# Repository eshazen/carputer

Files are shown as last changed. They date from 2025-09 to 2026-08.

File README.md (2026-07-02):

# carputer

Car computer with display and GPS in DIN enclosure

Proposed functions:

* Clock (updated by GPS)
* Nearest town and potentially other geographical features
* Outside temperature

Front panel would have a display, a couple of buttons/knobs
and a USB plug for power from the stereo plus software updates
using Arduino boot loader.

See (Data/README.md)[Data/README.md] for data details and ideas.

## Implementation notes

On the MKR Zero board, there are only a few pins which can be used for
interrupts.  See
[docs](https://docs.arduino.cc/language-reference/en/functions/external-interrupts/attachInterrupt/).
These pins are: 0, 1, 4, 5, 6, 7, 8, 9, A1, A2.

Unfortunately the encoder is connected to 11 and 12.  Pin 7 is unused,
but one interrupt doesn't do the trick.

So far no luck getting timer interrupts to work on the MKR zero.
Best bet seems to be the `Adafruit_ZeroTimer` but even though the
example works it seems to crash when trying to run e.g. SPI after setup.

## User Interface

First version displays 3 lines of nearest towns, with a status
line below with GMT time, GPS status and number of satellites.
Controls not implemented yet.

### Enhancements:

**V3.x**

* Hierarchy of search (state first, then state-specific towns?)
* Simple UI (button/knob to enable/disable debug mode)

**Other**

* Categories of POI, selected by knob
  <br>with timeout to return to town display?
* Clock time in local time zone (how to determine time zone?)
* Analog clock display
* Scrolling of long place names?

## Resources

See [https://github.com/eshazen/town_ident](https://github.com/eshazen/town_ident)
for a preliminary version based on ATMega328.

## Hardware

* **CPU** - Arduino MKR Zero.  SAMD21 cpu with 256k flash and 32k ram.  32-bit M0 core at 48MHz.
* **Display** - OLED with 3.12 inch 256x64 display.  Amazon:  [https://a.co/d/5zJTbLo](https://a.co/d/5zJTbLo)
* **GPS** - NEO-6M module (Amazon: [link](https://a.co/d/gSQQ6ZD).  The NEO-7M is a higher-performance replacement
* **Antenna** - Bingfu Waterproof "Active" GPS antenna SMA (Amazon: [link](https://a.co/d/aN1YYik).

### Display details

Ordered this 3.12" OLED with 16-pin connector from 
Asked ChatGPT for a pinout and it came up with [this](https://chatgpt.com/share/68c1a13d-e6dc-8000-bd67-d93712c7cb28).

Also see [ER-OLEDM028-1_Interfacing.pdf](Docs/ER-OLEDM028-1_Interfacing.pdf).

Link to
[Datasheet](https://newhavendisplay.com/content/specs/NHD-3.12-25664UCY2.pdf) for DigiKey version.

Beeped out from ours

| Function | Pin | | Pin | Function |
|---|-----|---|-----|---|
| GND | 1 | | 2 | ?VCC |
| ? | 3 | | 4 | D0 (SCLK?) |
| D1 (SDIN?) | 5 | | 6 | D2 |
| D3 | 7 | | 8 | D4 |
| D5 | 9 | | 10  | D6 |
| D7 | 11  | | 12  | E/RD |
| R/W | 13  | | 14  | DC |
| RES | 15  | | 16  | CS |
| | | | | |

See https://www.hicenda.com/product/312-inch-oled-module-01.html

Finally, referring to a datasheet: https://docs.rs-online.com/6267/0900766b8162af09.pdf
for the display itself with 30 pin flex, we can wring out the pinout with a meter.

Library candidates:

* [SSD1322_for_Adafruit_GFX](https://github.com/venice1200/SSD1322_for_Adafruit_GFX)
* [SSD1322_OLED_library](https://github.com/wjklimek1/SSD1322_OLED_library)

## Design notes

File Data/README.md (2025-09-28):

# Data

## Downloading, extraction

Downloaded and extracted places database from:
<br>(https://www2.census.gov/geo/tiger/TIGER2023/PLACE/)[https://www2.census.gov/geo/tiger/TIGER2023/PLACE/]

Using perl scripts `get_all_states.pl` and `extract_all_states.pl`.

Each zip file is named with a two-digit "FIPS" code.  These are listed in a nice
table along with the two-letter state abbreviation [here](https://www.bls.gov/respondents/mwr/electronic-data-interchange/appendix-d-usps-state-abbreviations-and-fips-codes.htm).

Converted via spreadsheet to `fips.csv`.

Used perl script `place_to_csv.pl` to create `places.csv`, like so:

    1,"Fernandina Beach",FL, +30.6579158, -081.4500012
    1,"Orlando",FL, +28.4728185, -081.3202421
    1,"Zolfo Springs",FL, +27.4925788, -081.7867927
    1,"Webster",FL, +28.6131310, -082.0512979
    1,"Islamorada, Village of Islands",FL, +24.9843519, -080.5432960
    1,"Marathon",FL, +24.7323382, -081.0251218
    1,"Layton",FL, +24.8251313, -080.8116238

NOTE! There are a few commas inside the quoted strings.

Suggest to include a "type" code so we can later include
other points of interest.

```
Codes:
1    - town name with state
```

Used a C program `index_file_offsets` to create a list of `long` offsets in
`places.csv` where each line starts.  This could be stored as a binary file
on the uSD card for quick access to any record by record#.

## Processing

We want to display the nearest few items of any given type.
It takes ~60s to traverse `places.csv` and calculate the great circle
distance to each from the current location.

All places are assigned to cells on a grid as described below.
For example, a 0.5 x 0.5 degree cell (25 x 34 miles).

The `places.csv` file is sorted by grid location.
An index file `gindex.dat` contains the offset
of the start of each group in the places file, as a list
of `NumLat*NumLon` 32-bit binary values for fast access.

## Files

### `places.csv`

This file contains a list of all places to be displayed.
Places are assigned to rectangular rid squares (last two columns).

| Number | Name | Description |
|---|---|---|
| 1 | type | Type ID (currently all are '1') |
| 2 | name | Name of place (quoted) |
| 3 | state | State abbreviation |
| 4 | lat | Latitude, signed decimal |
| 5 | lon | Longitude, signed decimal |
| 6 | lat_grid | Latitude grid cell number |
| 7 | lon_gird | Longitude grid cell number |

Sample data:

    Type,Name,State,Lat,Lon,LatG,LonG
    1,"Rehobeth",AL,   31.122548,  -85.439648,55,157
    1,"Coosada",AL,   32.495394,  -86.326543,60,153
    1,"Elmore",AL,   32.556606,  -86.341025,61,153
    1,"Wetumpka",AL,   32.542018,  -86.205307,61,154
    1,"Adamsville",AL,   33.602315,  -86.971527,65,151

### `grid.csv`

This file contains the grid info.
For example, grid (0,0) would be in the range:
<br>Latitude  between 17.25 and 17.50
<br>Longitude between -124.75 and -124.50

    NumLat, LatMin, LatMax, LatStep, NumLon, LonMin, LonMax, LonStep
    130,    17.25,  49.5,   0.25,    243,   -124.75, -64.25, 0.25

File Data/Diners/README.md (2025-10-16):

With considerable help from ChatGPT:

## How to run & download CSV (Overpass Turbo web UI)
* Open: https://overpass-turbo.eu/
* In the editor, replace the default text with the query above.
* Click Run (the lightning bolt). The matching objects will be fetched and shown on the map.
* After it finishes, click the Export button → choose download/copy as CSV (Overpass Turbo will generate the CSV using the out:csv specification). Save the file to your computer.
* If Overpass Turbo displays a size/timeout warning, reduce the radius or run the query in smaller geographic tiles (I can provide a tiled query script if needed).

```
[out:csv(::id, type, name, amenity, cuisine, "addr:street", "addr:housenumber", "addr:city", ::lat, ::lon; true; ",")][timeout:180];
(
  node["name"~"[Dd]iner"](around:48280,42.332137,-71.121679);
  way["name"~"[Dd]iner"](around:48280,42.332137,-71.121679);
  relation["name"~"[Dd]iner"](around:48280,42.332137,-71.121679);
);
out center;
```

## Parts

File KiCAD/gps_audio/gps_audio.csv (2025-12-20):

Reference | Qty | Value | Footprint | Datasheet | CatNo
A1 | 1 | Arduino_MKR_Zero_Socket | PCB_arduino-library:Arduino_MKR_Zero_Socket | https://docs.arduino.cc/hardware/mkr-zero | 732-5325-ND
C1,C4 | 2 | .047uF | Capacitor_THT:C_Disc_D7.0mm_W2.5mm_P5.00mm | ~ | BC2686CT-ND
C2,C3 | 2 | 250uF | Capacitor_THT:CP_Radial_D6.3mm_P2.50mm | ~ | 1189-2913-ND
C5 | 1 | 33uF | Capacitor_THT:CP_Radial_Tantal_D4.5mm_P5.00mm | ~ | 478-TAP336M010CRWCT-ND
J1 | 1 | Conn_01x05 | my_gps:gps_module | ~ | S7038-ND
LS1 | 1 | Speaker | speaker:CVS-1508_CUD | ~ | 102-2498-ND
N1 | 1 | Housing |  | ~ | 732-5325-ND
R1 | 1 | 10 | Resistor_THT:R_Axial_DIN0207_L6.3mm_D2.5mm_P10.16mm_Horizontal | ~
RV1 | 1 | R_Potentiometer | Potentiometer_THT:Potentiometer_Bourns_3266W_Vertical | ~ | 3266W-103LF-ND
U1 | 1 | LM386 | Package_DIP:DIP-8_W7.62mm | http://www.ti.com/lit/ds/symlink/lm386.pdf | 5536-LM386N-ND

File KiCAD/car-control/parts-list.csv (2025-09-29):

Reference | Value | Qty | DNP | CatNo | MfgNo
C1 | 0.1uF | 1 |  | 399-C1206C104K5RAC7800CT-ND | C1206C104K5RAC7800
D1,D2 | LED | 2 |  | 732-5013-ND | 151033RS03000
DS1 | RC1602A | 1 |  | 4411-CN0293-ND | CN0293
J1 | Conn_02x03_Odd_Even | 1 |  | 2057-PH2-06-UA-ND | PH2-06-UA
J2 | Conn_01x06 | 1 |  | 2057-PH1-06-UA-ND | PH1-06-UA
N1 | Knob | 1 |  | 1568-1838-ND | COM-10597
R1 | 10k | 1 |  | 311-10.0KFRCT-ND | RC1206FR-0710KL
R2,R5,R6 | 470 | 3 |  | A106077CT-ND | CRG1206F470R
R3,R4 | 3.3k | 2 |  | ~ | ~
RV1 | 10k | 1 |  | 3266W-103LF-ND | 3266W-1-103LF
SW1,SW2,SW3,SW4 | SW_Push | 4 |  | CH160-ND | MX1A-11NW
SW5 | COM-15140 | 1 |  | PEL12D-4225S-S2024-ND | PEL12D-4225S-S2024
U3 | ATmega328-P | 1 |  | ATMEGA328P-PU-ND | ATMEGA328P-PU

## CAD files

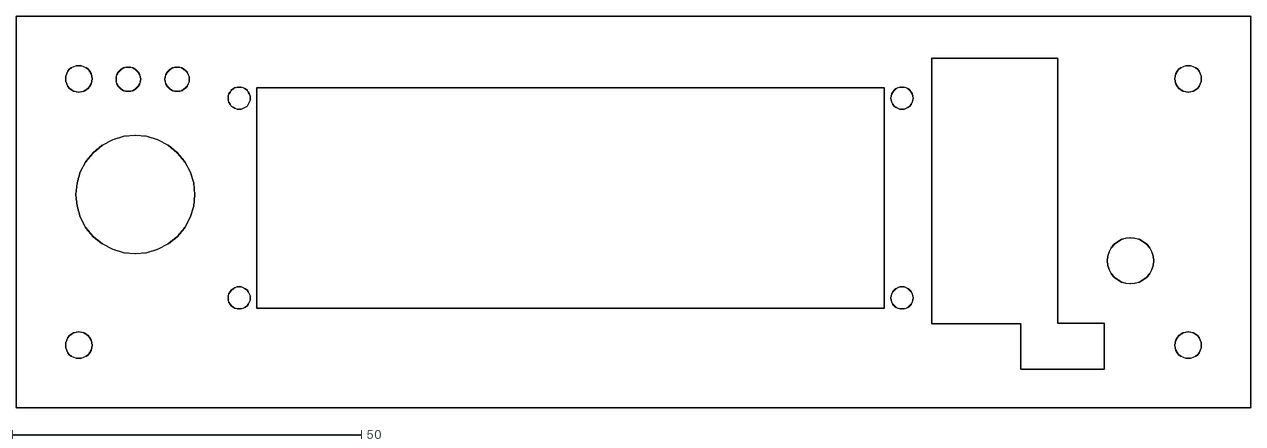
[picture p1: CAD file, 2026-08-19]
Case/front_panel.dxf
176.7 x 56.1

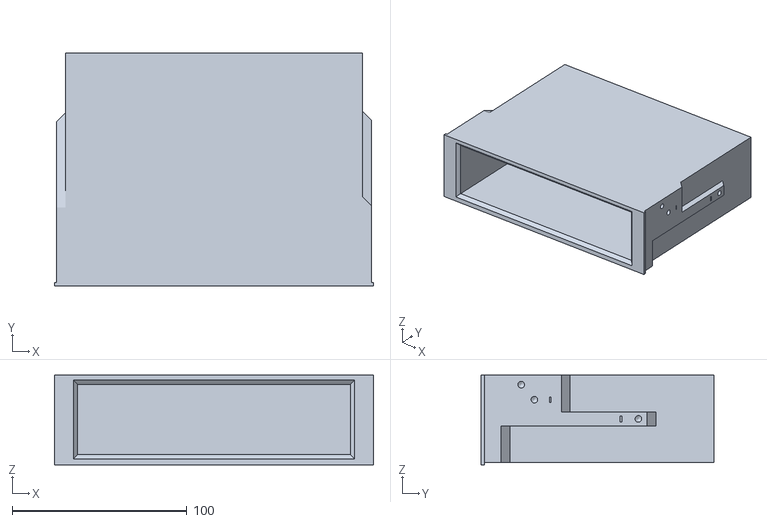
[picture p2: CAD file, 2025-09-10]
Case/OPs/Single_Din_Pocket.stl
182.5 x 133.2 x 51.2

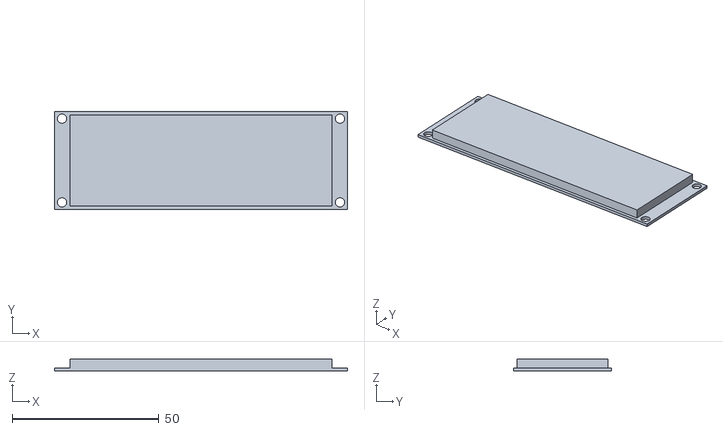
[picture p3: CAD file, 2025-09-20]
KiCAD/car-control/3D/oled.stl
100.0 x 33.4 x 4.17

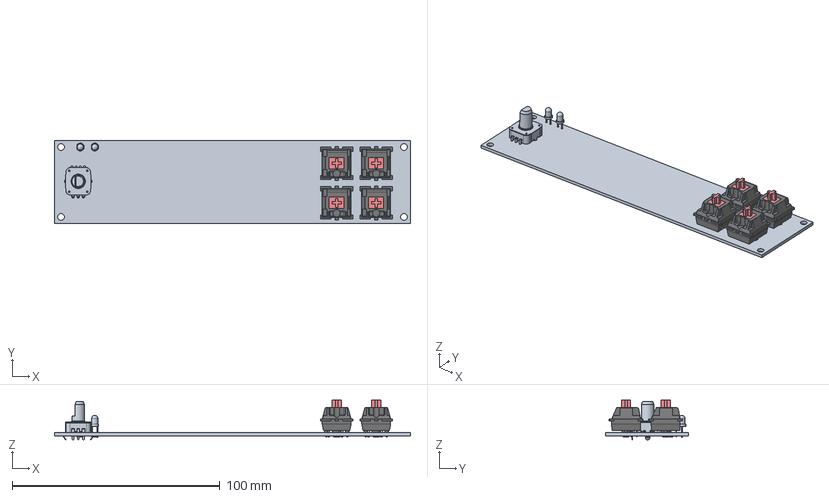
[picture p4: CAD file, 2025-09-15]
KiCAD/car-control/car-control.step
171.4 x 40.0 x 19.2 mm
EC12 Encoder 10mm 3pin
LED_D3.0mm x 2
R_1206_3216Metric x 2
control-panel_PCB

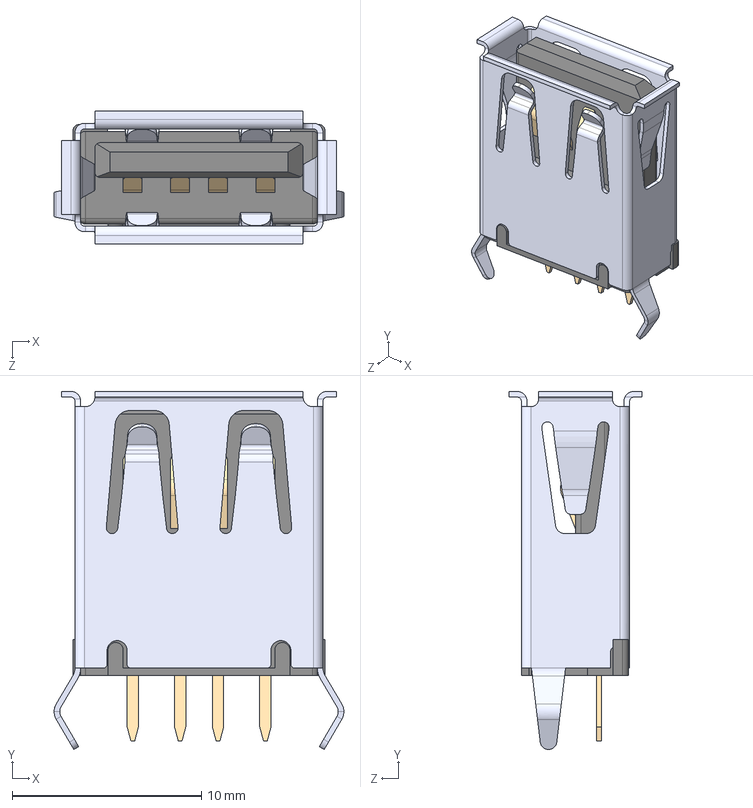
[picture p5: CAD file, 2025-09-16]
KiCAD/car-control/models/USB-A-S-F-B-VT--3DModel-STEP-269445.STEP
15.3 x 18.9 x 7.00 mm

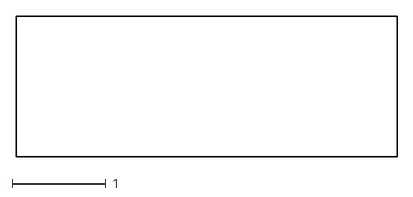
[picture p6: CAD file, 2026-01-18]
KiCAD/gps_audio/DXF/gps_audio-Edge_Cuts.dxf
4.07 x 1.50

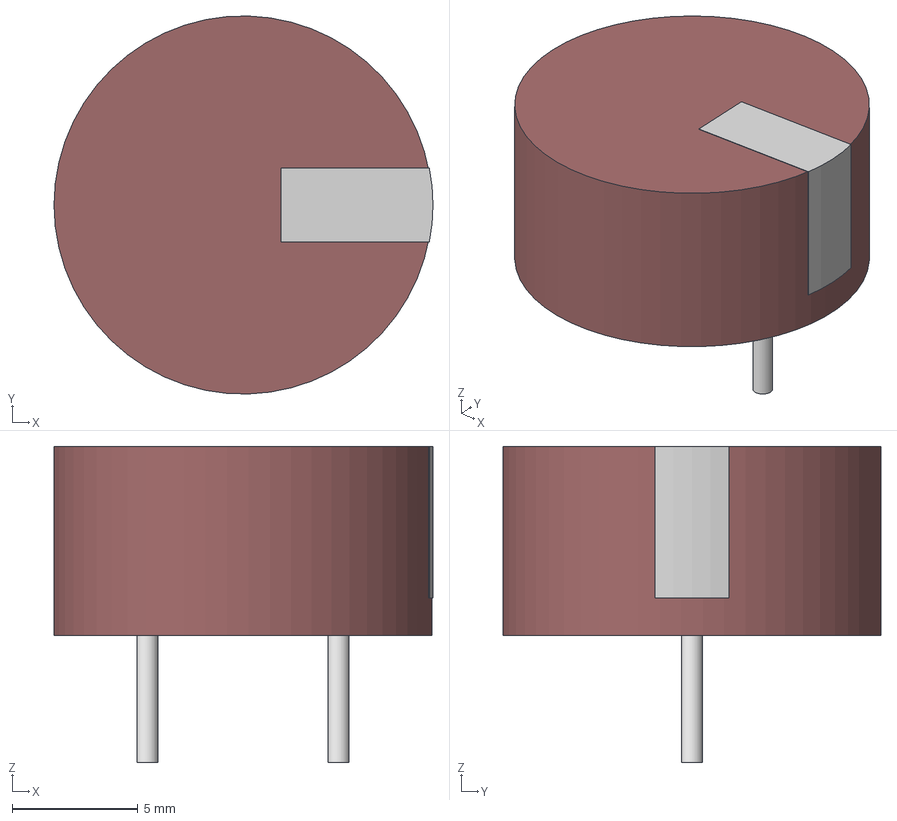
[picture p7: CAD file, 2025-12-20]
KiCAD/gps_audio/models/CVS-1508_CUD.step
15.0 x 15.0 x 12.6 mm

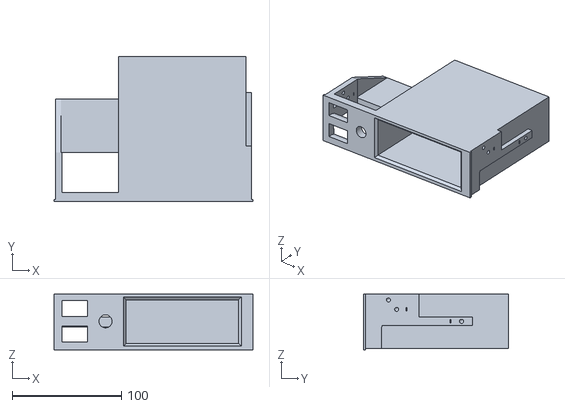
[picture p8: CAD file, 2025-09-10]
Case/OPs/Single_Din_with_Switch_and_LCD.stl
182.5 x 133.2 x 51.2

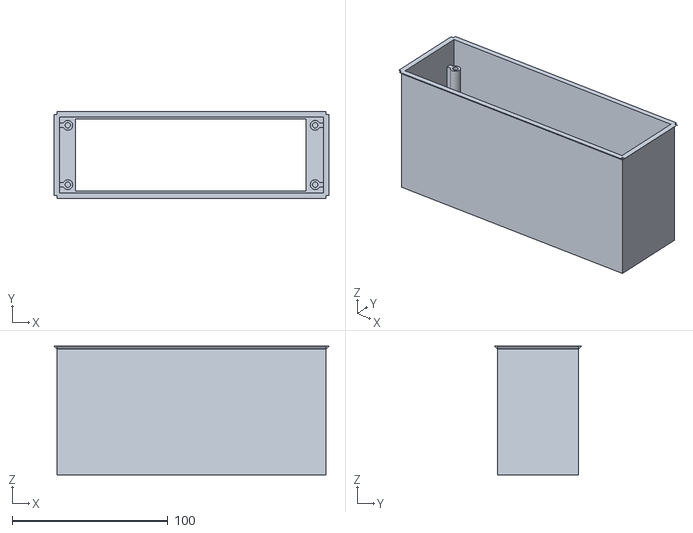
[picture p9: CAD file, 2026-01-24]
Case/puter.stl
176.5 x 55.9 x 82.6

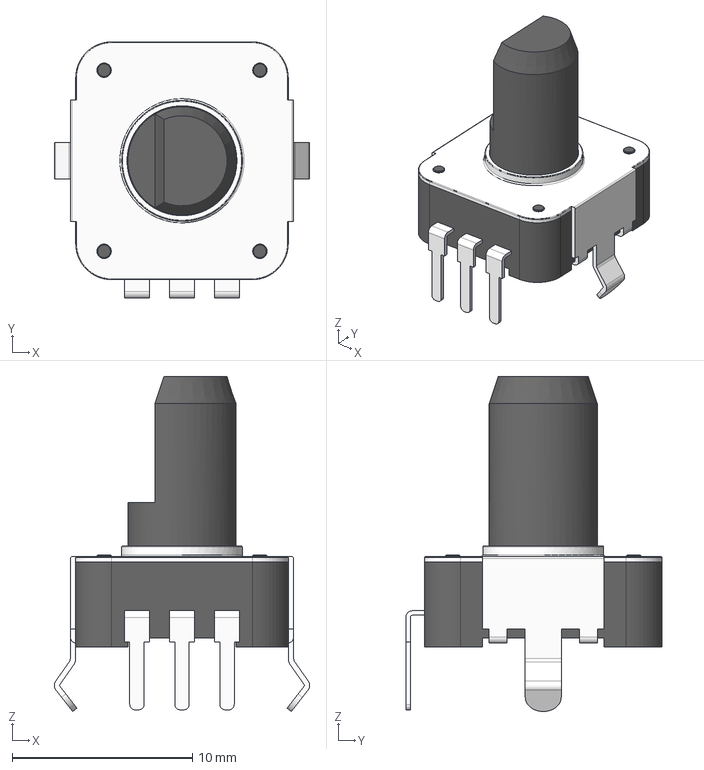
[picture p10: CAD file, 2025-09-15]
KiCAD/car-control/3D/EC12 Encoder 10mm 3pin.stp
14.2 x 14.2 x 18.6 mm

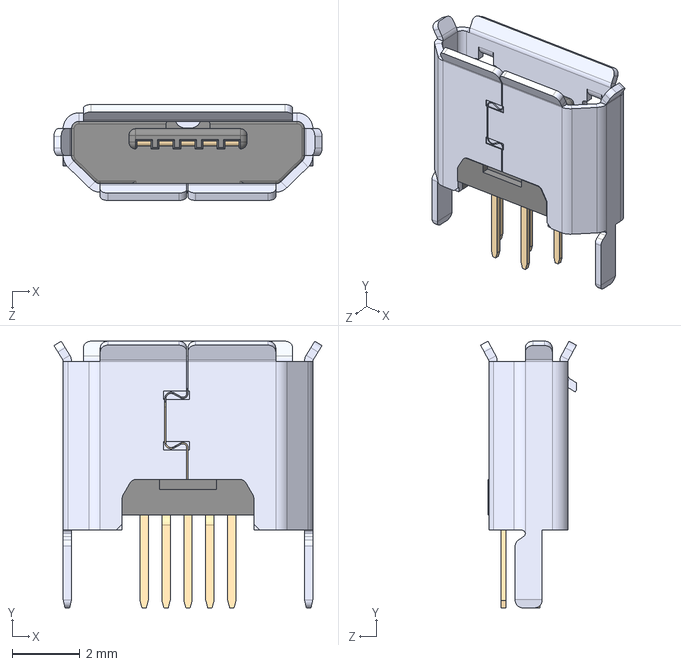
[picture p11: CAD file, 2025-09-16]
KiCAD/car-control/models/USB3131-30-0230-A_REVB.step
7.94 x 7.90 x 2.84 mm

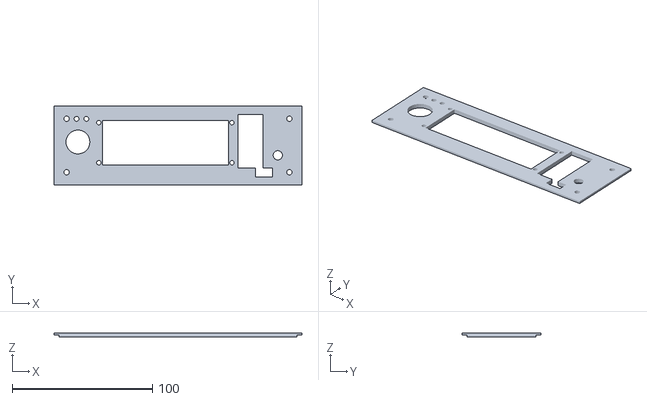
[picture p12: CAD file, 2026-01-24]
Case/panel.stl
176.7 x 56.1 x 3.10

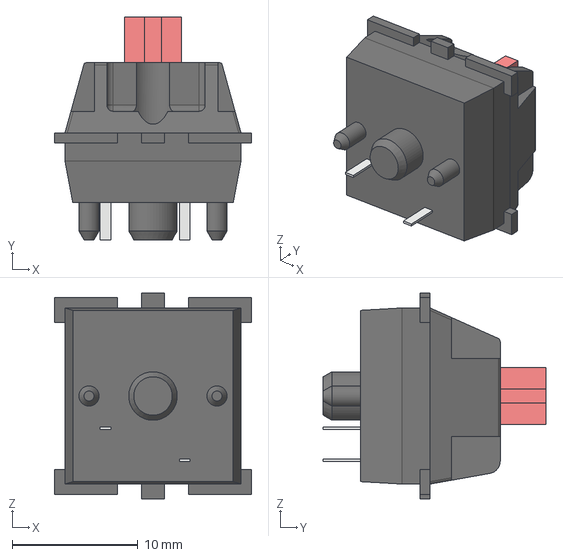
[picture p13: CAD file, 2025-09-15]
KiCAD/car-control/3D/switch.step
15.6 x 17.7 x 16.3 mm

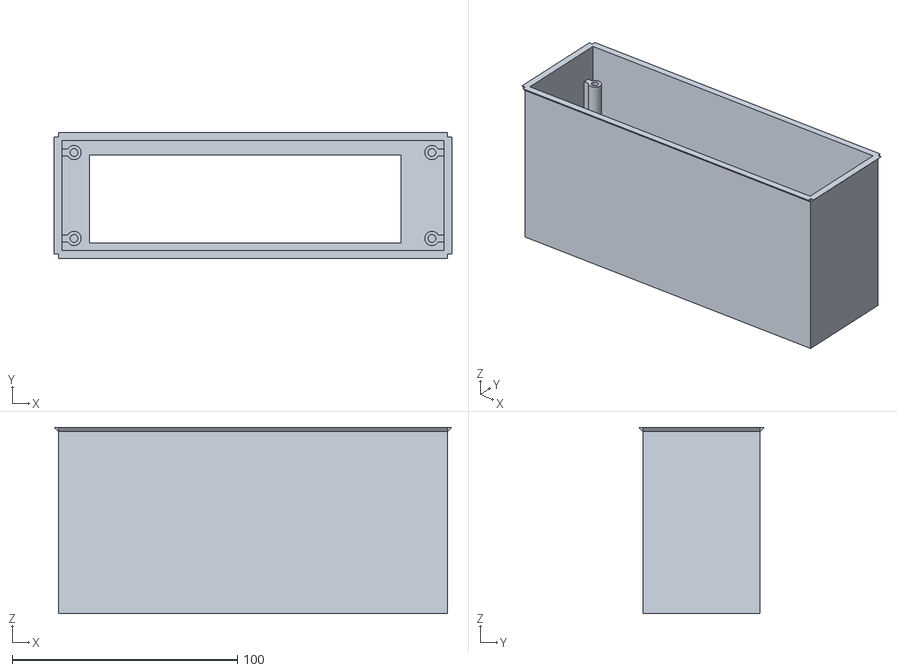
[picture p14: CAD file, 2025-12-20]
Case/box.stl
176.5 x 55.9 x 82.6

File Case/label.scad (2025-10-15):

//
// car computer enclosure
//
// TODO:  move GPS antenna hole to match PCB hole
//        add contrasting text on front panel?
//        re-print front panel
//
//        Consider re-printing box with standoff change
//

mm = 25.4;
$fn = 32;
e = 0.1;

include <oled.scad>

module tri_prism( width, height, length) {
     polyhedron(
	  points = [ [0,0,0], [0,height,0], [width,0,0], 
		     [0,0,length], [width, 0, length], [0,height,length]],
	  faces = [ [0, 1, 2], [3, 4, 5], [0, 2, 4, 3],
		    [0, 3, 5, 1], [1, 5, 4, 2]],
	  convexity = 10);
}

//
// case body
//
// body_spc = 0.05*mm;
body_spc = 0.075*mm;

body_w = 6.875*mm-body_spc;
body_h = 2.125*mm-body_spc;

//--- normal
// body_d = 2.5*mm;
body_d = 3.25*mm;  // add room for USB connector


// pcb_standoff_down = 0.25*mm + 0.7*mm;   // as last printed
pcb_standoff_down = 0.7*mm;	// proposed update remove standoffs

//--- fast print
//body_d = 10;     /* fast print */
//pcb_standoff_down = 2;

body_thk = 1.6;
body_lip = 2.0;

panel_w = body_w + 2*body_lip;
panel_h = body_h + 2*body_lip;

panel_w_in = body_w-2*body_thk;
panel_h_in = body_h-2*body_thk;

// PCB mounting holes
pcb_hole_dx = 6.25*mm;
pcb_hole_dy = 1.5*mm;
// pcb_hole_dia = 0.098*mm;	/* 4-40 tap drill */
pcb_hole_dia = 0.140*mm;	/* 6-32 test fit */
pcb_standoff_dia = 0.25*mm;


panel_hole_dia = 0.15*mm;

pcb_so_supp_wid = 3;
pcb_so_supp_len = pcb_hole_dia/2+6-body_spc/2;

module standoff_at( x, y, dia, hole, hgt, rot) {
    translate( [x, y, 0]) {
      rotate( [0, 0, rot]) {
      difference() {
	union() {
	  cylinder( d=dia, h=hgt);
	  translate( [-pcb_so_supp_wid/2, -pcb_so_supp_len, 0])
	    cube( [pcb_so_supp_wid, pcb_so_supp_len, hgt]);
	}
	translate( [0, 0, -e])
	  cylinder( d=hole, h=hgt+2*e);
      }
    }
  }
}

// draw a lip, angled for no support
module lip() {
     translate( [body_w, body_h-e, body_d])
	  rotate( [90, 180, 270])
	  tri_prism( body_lip, body_lip, body_w);
     translate( [0, e, body_d])
	  rotate( [90, 180, 90])
	  tri_prism( body_lip, body_lip, body_w);
     translate( [body_w-e, 0, body_d])
	  rotate( [90, 180, 180])
	  tri_prism( body_lip, body_lip, body_h);
     translate( [e, body_h, body_d])
	  rotate( [90, 180, 0])
	  tri_prism( body_lip, body_lip, body_h);
     
}

// draw box with lip, centered
module box() {
     translate( [-body_w/2, -body_h/2, -body_d])
     difference() {
	  union() {
	       // box body
	       echo("Box ", body_w, ", ", body_h);
	       cube( [body_w, body_h, body_d]);
	       color("red") lip();
//	       // lip
//	       translate( [-body_lip, -body_lip, body_d-body_thk])
//		    cube( [body_w+2*body_lip, body_h+2*body_lip, body_thk]);
	  }
	  // cavity
	  translate( [body_thk, body_thk, body_thk])
	       cube( [body_w-2*body_thk, body_h-2*body_thk, body_d]);
	  // wiring hole
	  translate( [4*body_w/5, body_h/2, -e])
	       cylinder( d=0.375*mm, h=10);
	  echo("Cavity (mm)", body_w-2*body_thk, body_h-2*body_thk, body_d);
	  echo("Cavity (in)", (body_w-2*body_thk)/mm, (body_h-2*body_thk)/mm, body_d/mm);
     }

     translate( [0, 0, -body_d+body_thk-e]) {
       standoff_at( -pcb_hole_dx/2, -pcb_hole_dy/2, pcb_standoff_dia, pcb_hole_dia, body_d-pcb_standoff_down, 270); 
       standoff_at( -pcb_hole_dx/2, pcb_hole_dy/2, pcb_standoff_dia, pcb_hole_dia, body_d-pcb_standoff_down, 270);
       standoff_at( pcb_hole_dx/2, -pcb_hole_dy/2, pcb_standoff_dia, pcb_hole_dia, body_d-pcb_standoff_down, 90); 
       standoff_at( pcb_hole_dx/2, pcb_hole_dy/2, pcb_standoff_dia, pcb_hole_dia, body_d-pcb_standoff_down, 90);
    }
}

module mounting_holes() {
  translate( [-pcb_hole_dx/2, -pcb_hole_dy/2, 0]) cylinder( h=20, d=panel_hole_dia);
  translate( [-pcb_hole_dx/2, pcb_hole_dy/2,  0]) cylinder( h=20, d=panel_hole_dia);
  translate( [pcb_hole_dx/2, -pcb_hole_dy/2,  0]) cylinder( h=20, d=panel_hole_dia);
  translate( [pcb_hole_dx/2, pcb_hole_dy/2, 0]) cylinder( h=20, d=panel_hole_dia);
}


// front panel, centered

module panel() {
  translate( [-panel_w/2, -panel_h/2, 0]) {
    cube( [panel_w, panel_h, body_thk]);
    translate( [body_lip+body_thk, body_lip+body_thk, -body_thk+e])
      cube( [panel_w_in, panel_h_in, body_thk]);
  }
     
}

// holes for switches, knob, LEDs, USB
module button_holes() {
  // LEDs
  translate( [-115, 35, 0])  
    cylinder( d=3.5, h=20);
  translate( [-108, 35, 0])  
    cylinder( d=3.5, h=20);
  // knob
  translate( [-114, 18.5, 0])
    cylinder( d=17, h=20);
  // left 2 switches
  cube( [18, 38, 20]);
  // USB
  translate( [12.7, -6.5, 0])
    cube( [12, 0.26*mm, 20]);
}

// front panel with holes
translate( [0,0,16]) {
  color("#303030")
  difference() {
    panel();
    translate( [0, 0, -5]) {
      translate( [-9,2,0]) oled_holes();
      mounting_holes();
      translate( [42.7, -16, 0])
      button_holes();
    }
    // Antenna hole
    translate( [pcb_hole_dx/2-0.325*mm, -pcb_hole_dy/2+0.475*mm, -5]) cylinder( h=20, d=0.26*mm);
  }
  // text
  
  translate( [0, 0, body_thk-e]) {
    translate( [-body_w/2-0.5, body_h/2-4.4, 0]) {
      color("white") linear_extrude( height=0.8)
	text("TownFinder", 5);
      translate( [36, 2, 0])
	color("white") linear_extrude( height=0.8)
	text("TM", 3);
    }
  }
}


// box();

// translate( [0, 0, 5]) {
//      difference() {
//        	  color("brown") panel();
// 	  translate( [-body_w+0.65*mm, 70, 0])
// 	       translate( [147.5, -69.7, 0]) oled_holes();
//      }
// }
// 
// 

// translate( [-body_w+0.62*mm, 71.8, 10]) {
//       color("green") import("car-control.stl");
//       translate( [147.5, -69.9, 3]) oled();
// }

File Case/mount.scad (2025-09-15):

//
// Miata NA dual-opening DIN mount
//

mm = 25.4;
e = 0.1;
$fn = 32;

fast = 1;

// DIN opening 
//din_w = 7.25*mm;		/* width */
din_w = 7.187*mm;		/* width */
din_h = 2.125*mm;		/* height */
din_d = 1*mm;		/* depth */
// din_d = 0.25*mm;		/* fast test depth */

din_thk = 0.1*mm;		/* DIN wall thickness */

overall_h = 4.75*mm;
overall_w = 7.375*mm;

frame_thk = 0.125*mm;

din_hgt = din_h + 2*din_thk;
din_wid = din_w + 2*din_thk;

din_c2c = overall_h-din_hgt;

// supports
supp_x = 1.625*mm;
supp_w = 0.5*mm;
supp_h = din_thk;
// supp_l = 1*mm;
supp_l = 0.35*mm;		/* fast test */

// bracket 
bkt_w = 0.5*mm;
bkt_h = 0.6*mm;
bkt_t = 0.125*mm;
bkt_hole = 0.225*mm;
bkt_slot = 0.4*mm-bkt_hole;

// top_bkt = 1.063*mm;
top_bkt = 0.938*mm;
bot_bkt = 0.688*mm;

// DIN opening only
module din_open() {
     translate( [din_thk-din_wid/2, din_thk-din_hgt/2, -e])
	  cube( [din_w, din_h, din_d+2*e]);
}

// Two openings centered
module din_open2() {
     translate( [0, -din_c2c/2, 0]) {
	  din_open();
	  translate( [0, din_c2c, 0]) din_open();
     }
}

// outer frame, solid, centered
module outer() {
     translate( [-overall_w/2, -overall_h/2, 0]) {
	  cube( [overall_w, overall_h, din_d]);
     }
}

// one support
module support() {
     cube( [supp_w, supp_h, supp_l]);
}

// left, right and bottom supports
module supports() {
     translate( [-overall_w/2+supp_x-supp_w/2, overall_h/2-supp_h, -supp_l+e])
	  support();
     translate( [overall_w/2-supp_x-supp_w/2, overall_h/2-supp_h, -supp_l+e])
	  support();
     translate( [-overall_w/2+din_thk, overall_h/2-top_bkt-bkt_h/2, -supp_l+e])
	  rotate([0,0,90]) support();
     translate( [overall_w/2-din_thk+supp_h, overall_h/2-top_bkt-bkt_h/2, -supp_l+e])
	  rotate([0,0,90]) support();
}

// one mounting bracket with oval hole
module bracket() {
     difference() {
	  translate( [-bkt_w/2, -bkt_h/2, 0]) cube( [bkt_w, bkt_h, bkt_t]);
	  translate( [0, -bkt_slot/2, -e]) cylinder( d=0.225*mm, h=bkt_t+2*e);
	  translate( [0, bkt_slot/2, -e]) cylinder( d=0.225*mm, h=bkt_t+2*e);
	  translate( [-bkt_hole/2, -bkt_slot/2, -e]) cube( [bkt_hole, bkt_slot, bkt_t+2*e]);
     }
}

// four mounting brackets
module brackets() {
     translate( [-overall_w/2-bkt_w/2+e, overall_h/2-top_bkt, 0]) bracket();
     translate( [overall_w/2+bkt_w/2-e, overall_h/2-top_bkt, 0]) bracket();

     translate( [-overall_w/2-bkt_w/2+e, -overall_h/2+bot_bkt, 0]) bracket();
     translate( [overall_w/2+bkt_w/2-e, -overall_h/2+bot_bkt, 0]) bracket();
}

cut1_x = 38;
cut1_dx = 15;

cut2_x = 129;
cut2_dx = 15;

// din_cut = 15;
din_cut = 10;


// frame with DIN openings
difference() {
     outer();
     din_open2();
     translate( [-din_w/2-cut1_x, -10, -din_cut])
	  cube( [cut1_dx, 20, 20]);
     translate( [-din_w/2+cut1_x, -10, -20+din_cut])
	 cube( [cut1_dx, 20, 20]);
     translate( [-din_w/2+cut2_x, -10, -20+din_cut])
	 cube( [cut2_dx, 20, 20]);
}


brackets();
// supports();

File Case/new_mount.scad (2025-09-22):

//
// Miata NA dual-opening DIN mount
// reboot with more attention to detal
//
// note that bottom opening is narrower
//

mm = 25.4;
e = 0.1;
$fn = 32;

thin = 0;

// DIN opening 
din_w = 7.187*mm;		/* width - upper opening for radio */
din_w2 = 6.875*mm;
din_h = 2.125*mm;		/* height */
din_d = 1*mm;		/* depth */
// din_d = 0.5*mm;		/* fast test depth */

din_thk = 0.1*mm;		/* DIN wall thickness */

overall_h = 4.75*mm;
overall_w = 7.375*mm;

lower_w = 7.1875*mm;		/* lower bay overall width 7-3/16 */
lower_h = 2.25*mm;		/* lower bay height of narrower frame portion */

lower_w2 = 7.0625*mm;		/* bottom narrowing to fit panel opening */

upper_h = overall_h-lower_h;
side_cut_d = 0.4*mm;

w_diff = overall_w-lower_w;

frame_thk = 0.125*mm;

din_hgt = din_h + 2*din_thk;
din_wid = din_w + 2*din_thk;

din_c2c = overall_h-din_hgt;

// supports
supp_x = 1.625*mm;
supp_w = 0.5*mm;
supp_h = din_thk;
supp_l = 1*mm;
//supp_l = 0.35*mm;		/* fast test */

// bracket 
bkt_w = 0.5*mm;
bkt_h = 0.6*mm;
bkt_t = 0.125*mm;
bkt_hole = 0.225*mm;
bkt_slot = 0.4*mm-bkt_hole;

// upper bracket
ubkt_w = 0.5*mm;
ubkt_h = 1.0*mm;
ubkt_t = 0.125*mm;

// top_bkt = 1.063*mm;
top_bkt = 0.938*mm;
bot_bkt = 0.688*mm;

// DIN opening specified with, height, centered
module din_open( wid, hgt) {
     translate( [-wid/2, -hgt/2, -e]) {
	  cube( [wid, hgt, din_d+2*e]);
     }
}

module test_open2() {
     translate( [0, -din_c2c/2, 0]) {
	  din_open( din_w, din_h);
	  translate( [0, din_c2c, 0]) din_open( din_w2, din_h);
     }
}


// Two openings centered
module din_open2() {
     translate( [0, -din_c2c/2, 0]) {
	  din_open( din_w, din_h);
	  translate( [0, din_c2c, 0]) din_open( din_w2, din_h);
     }
}

// outer frame, solid, centered
module outer() {
     translate( [-overall_w/2, -overall_h/2, 0]) {
	  cube( [overall_w, upper_h, din_d]);
	  translate( [(overall_w-lower_w)/2, upper_h, 0])
	       cube( [lower_w, lower_h, din_d]);
     }
}

// one support
module support() {
     cube( [supp_w, supp_h, supp_l]);
}

// left, right and bottom supports
module supports() {
     translate( [-overall_w/2+supp_x-supp_w/2, overall_h/2-supp_h, -supp_l+e])
	  support();
     translate( [overall_w/2-supp_x-supp_w/2, overall_h/2-supp_h, -supp_l+e])
	  support();
     translate( [-overall_w/2+din_thk, overall_h/2-top_bkt-bkt_h/2, -supp_l+e])
	  rotate([0,0,90]) support();
     translate( [overall_w/2-din_thk+supp_h, overall_h/2-top_bkt-bkt_h/2, -supp_l+e])
	  rotate([0,0,90]) support();
}

// one mounting bracket with oval hole
module bracket( d) {
     difference() {
	  translate( [-bkt_w/2, -bkt_h/2, 0]) cube( [bkt_w+d, bkt_h, bkt_t]);
	  translate( [0, -bkt_slot/2, -e]) cylinder( d=0.225*mm, h=bkt_t+2*e);
	  translate( [0, bkt_slot/2, -e]) cylinder( d=0.225*mm, h=bkt_t+2*e);
	  translate( [-bkt_hole/2, -bkt_slot/2, -e]) cube( [bkt_hole, bkt_slot, bkt_t+2*e]);
     }
}

// upper bracket
module up_bracket( d) {
     difference() {
	  translate( [-ubkt_w/2, -bkt_h/2, 0]) cube( [ubkt_w+d, ubkt_h, ubkt_t]);
	  // slot for reference
	  translate( [0, -bkt_slot/2, -e]) cylinder( d=0.225*mm, h=bkt_t+2*e);
	  translate( [0, bkt_slot/2, -e]) cylinder( d=0.225*mm, h=bkt_t+2*e);
	  translate( [-bkt_hole/2, -bkt_slot/2, -e]) cube( [bkt_hole, bkt_slot, bkt_t+2*e]);
	  // new mounting hole
	  translate( [0.135*mm, 0.405*mm, -e]) color("red") cylinder( d=4, h=10);
     }
}


// four mounting brackets
module brackets() {
     translate( [-overall_w/2-bkt_w/2+e, overall_h/2-top_bkt, 0]) bracket(3);
     translate( [overall_w/2+bkt_w/2-e, overall_h/2-top_bkt, 0]) rotate( [0,0,180]) bracket(3);

//     translate( [-overall_w/2-bkt_w/2+e, -overall_h/2+bot_bkt, 0]) up_bracket(0);
     translate( [overall_w/2+bkt_w/2-e, -overall_h/2+bot_bkt, 0]) up_bracket(3);
     mirror( [1, 0, 0])     translate( [overall_w/2+bkt_w/2-e, -overall_h/2+bot_bkt, 0]) up_bracket(3);
}

// side cuts next to top
module side_cut() {
     translate( [overall_w/2+7, -din_c2c+frame_thk-5, din_d-side_cut_d]) {
	  rotate( [0, 0, 90]) {
	       cube( [din_h+5, 14.4, side_cut_d+e]);
	  }
     }
}

module side_cuts() {
     side_cut();
     mirror( [1, 0, 0]) side_cut();
}

module narrow_cut() {
     translate( [-lower_w/2-5, frame_thk-8, din_d-side_cut_d+e])
	  cube( [(lower_w-lower_w2)/2+5, din_h+20, side_cut_d]);
}

module narrow() {
     narrow_cut();
     mirror( [1, 0, 0]) narrow_cut();
}

cut1_x = 38;
cut1_dx = 15;

cut2_x = 129;
cut2_dx = 15;

// din_cut = 15;
din_cut = 10;

module mount() {

// frame with DIN openings
     difference() {
	  outer();
	  din_open2();
	  side_cuts();
	  narrow();
	  translate( [-din_w/2+cut1_x, -10, -20+din_cut]) cube( [cut1_dx, 20, 20]);
	  translate( [-din_w/2+cut2_x, -10, -20+din_cut]) cube( [cut2_dx, 20, 20]);
     }

     brackets();
// supports();
}

ow = overall_w+40;
oh = overall_h+40;

// slice thin
if( thin == 1) {
     difference() {
	  mount();
	  translate( [-ow/2-e, -oh/2-e, 1.6])
	       cube( [ow+2*e, oh+3*e, 30]);
     }
} else {
     mount();
}

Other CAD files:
Case/standoff_test.stl
Case/box_fast.stl
Case/new_mount.3mf
Case/oled.scad
Case/Unnamed-MKRZero_V5.0.stl
Case/din.3mf
Case/din.stl
Case/mount.stl
Case/mount2.stl
Case/new_mount.stl
Case/puter.scad
Case/speaker_older.stl
Case/standoff_test.scad
Data/Shapefiles/BOSTON.PRT
Data/Shapefiles/COUNTY.PRT
Data/Shapefiles/MASS.PRT
Data/Shapefiles/NYBB.PRT
Data/Shapefiles/PLACE.PRT
Data/Shapefiles/STATES.PRT
Data/Shapefiles/STUFF.PRT
Data/Shapefiles/STUFFZ.PRT
Data/Shapefiles/ZONE.PRT
KiCAD/car-control/3D/LCD_16x2_sparkfun.scad
KiCAD/car-control/car-control.stl
KiCAD/gps_audio/DXF/gps_audio-F_Mask.dxf
KiCAD/gps_audio/DXF/gps_audio-F_Paste.dxf

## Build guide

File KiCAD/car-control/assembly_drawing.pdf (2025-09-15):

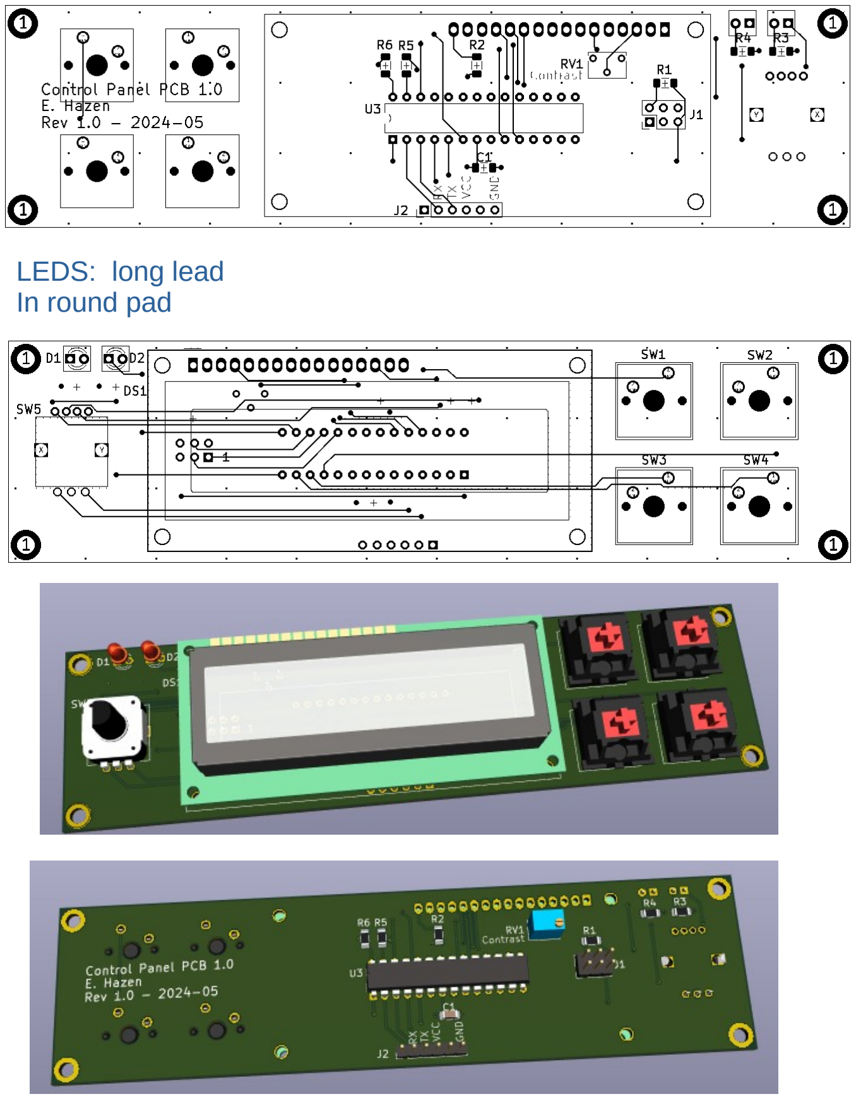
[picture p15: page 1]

LEDS: long lead
In round pad

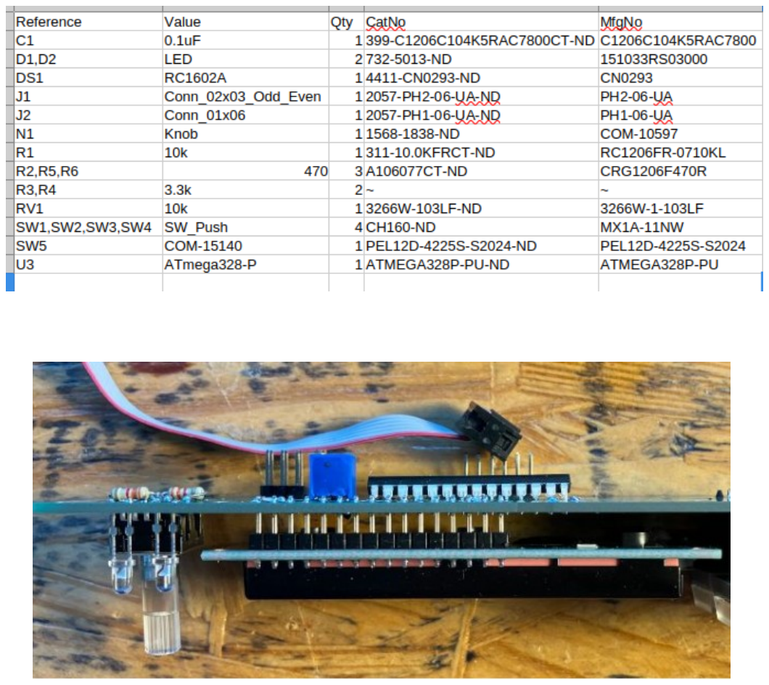
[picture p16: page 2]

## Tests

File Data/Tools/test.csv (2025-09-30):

1 | Rehobeth | AL | 31.1225 | -85.4396 | 15 | 39
1 | Coosada | AL | 32.4954 | -86.3265 | 16 | 38
1 | Elmore | AL | 32.5566 | -86.341 | 16 | 38
1 | Wetumpka | AL | 32.542 | -86.2053 | 16 | 38
1 | Adamsville | AL | 33.6023 | -86.9715 | 17 | 38
1 | Brookside | AL | 33.6374 | -86.8927 | 17 | 38
1 | Fultondale | AL | 33.6174 | -86.8014 | 17 | 38
1 | Helena | AL | 33.2845 | -86.8865 | 17 | 38
1 | Kimberly | AL | 33.777 | -86.8002 | 17 | 38
1 | Leeds | AL | 33.5468 | -86.5714 | 17 | 38
1 | Midfield | AL | 33.4553 | -86.9224 | 17 | 38
1 | Mountain Brook | AL | 33.4915 | -86.7345 | 17 | 38
1 | North Johns | AL | 33.3678 | -87.1007 | 17 | 37
1 | Madrid | AL | 31.0356 | -85.3992 | 15 | 39
1 | Sweet Water | AL | 32.1046 | -87.8619 | 16 | 37
1 | Faunsdale | AL | 32.4576 | -87.5938 | 16 | 37
1 | Geiger | AL | 32.8687 | -88.3182 | 16 | 36
1 | Millbrook | AL | 32.5015 | -86.3739 | 16 | 38
1 | Prattville | AL | 32.449 | -86.4494 | 16 | 38
1 | Eclectic | AL | 32.6402 | -86.0411 | 16 | 38
1 | Opp | AL | 31.2844 | -86.2574 | 15 | 38
1 | Excel | AL | 31.4264 | -87.3437 | 15 | 37
1 | Monroeville | AL | 31.5162 | -87.3277 | 15 | 37
1 | Vredenburgh | AL | 31.8232 | -87.3181 | 15 | 37
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

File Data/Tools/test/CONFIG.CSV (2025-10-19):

Type | File | Name
1 | TOWN | Towns
2 | AIRPORT | Airports
3 | DINER | Diners

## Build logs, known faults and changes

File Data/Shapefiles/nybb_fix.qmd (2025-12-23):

<!DOCTYPE qgis PUBLIC 'http://mrcc.com/qgis.dtd' 'SYSTEM'>
<qgis version="3.34.4-Prizren">
  <identifier></identifier>
  <parentidentifier></parentidentifier>
  <language></language>
  <type>dataset</type>
  <title></title>
  <abstract></abstract>
  <links/>
  <dates/>
  <fees></fees>
  <encoding></encoding>
  <crs>
    <spatialrefsys nativeFormat="Wkt">
      <wkt>PROJCRS["NAD83 / New York Long Island (ftUS)",BASEGEOGCRS["NAD83",DATUM["North American Datum 1983",ELLIPSOID["GRS 1980",6378137,298.257222101,LENGTHUNIT["metre",1]]],PRIMEM["Greenwich",0,ANGLEUNIT["degree",0.0174532925199433]],ID["EPSG",4269]],CONVERSION["SPCS83 New York Long Island zone (US survey foot)",METHOD["Lambert Conic Conformal (2SP)",ID["EPSG",9802]],PARAMETER["Latitude of false origin",40.1666666666667,ANGLEUNIT["degree",0.0174532925199433],ID["EPSG",8821]],PARAMETER["Longitude of false origin",-74,ANGLEUNIT["degree",0.0174532925199433],ID["EPSG",8822]],PARAMETER["Latitude of 1st standard parallel",41.0333333333333,ANGLEUNIT["degree",0.0174532925199433],ID["EPSG",8823]],PARAMETER["Latitude of 2nd standard parallel",40.6666666666667,ANGLEUNIT["degree",0.0174532925199433],ID["EPSG",8824]],PARAMETER["Easting at false origin",984250,LENGTHUNIT["US survey foot",0.304800609601219],ID["EPSG",8826]],PARAMETER["Northing at false origin",0,LENGTHUNIT["US survey foot",0.304800609601219],ID["EPSG",8827]]],CS[Cartesian,2],AXIS["easting (X)",east,ORDER[1],LENGTHUNIT["US survey foot",0.304800609601219]],AXIS["northing (Y)",north,ORDER[2],LENGTHUNIT["US survey foot",0.304800609601219]],USAGE[SCOPE["Engineering survey, topographic mapping."],AREA["United States (USA) - New York - counties of Bronx; Kings; Nassau; New York; Queens; Richmond; Suffolk."],BBOX[40.47,-74.26,41.3,-71.8]],ID["EPSG",2263]]</wkt>
      <proj4>+proj=lcc +lat_0=40.1666666666667 +lon_0=-74 +lat_1=41.0333333333333 +lat_2=40.6666666666667 +x_0=300000 +y_0=0 +ellps=GRS80 +towgs84=0,0,0,0,0,0,0 +units=us-ft +no_defs</proj4>
      <srsid>245</srsid>
      <srid>2263</srid>
      <authid>EPSG:2263</authid>
      <description>NAD83 / New York Long Island (ftUS)</description>
      <projectionacronym>lcc</projectionacronym>
      <ellipsoidacronym>EPSG:7019</ellipsoidacronym>
      <geographicflag>false</geographicflag>
    </spatialrefsys>
  </crs>
  <extent/>
</qgis>

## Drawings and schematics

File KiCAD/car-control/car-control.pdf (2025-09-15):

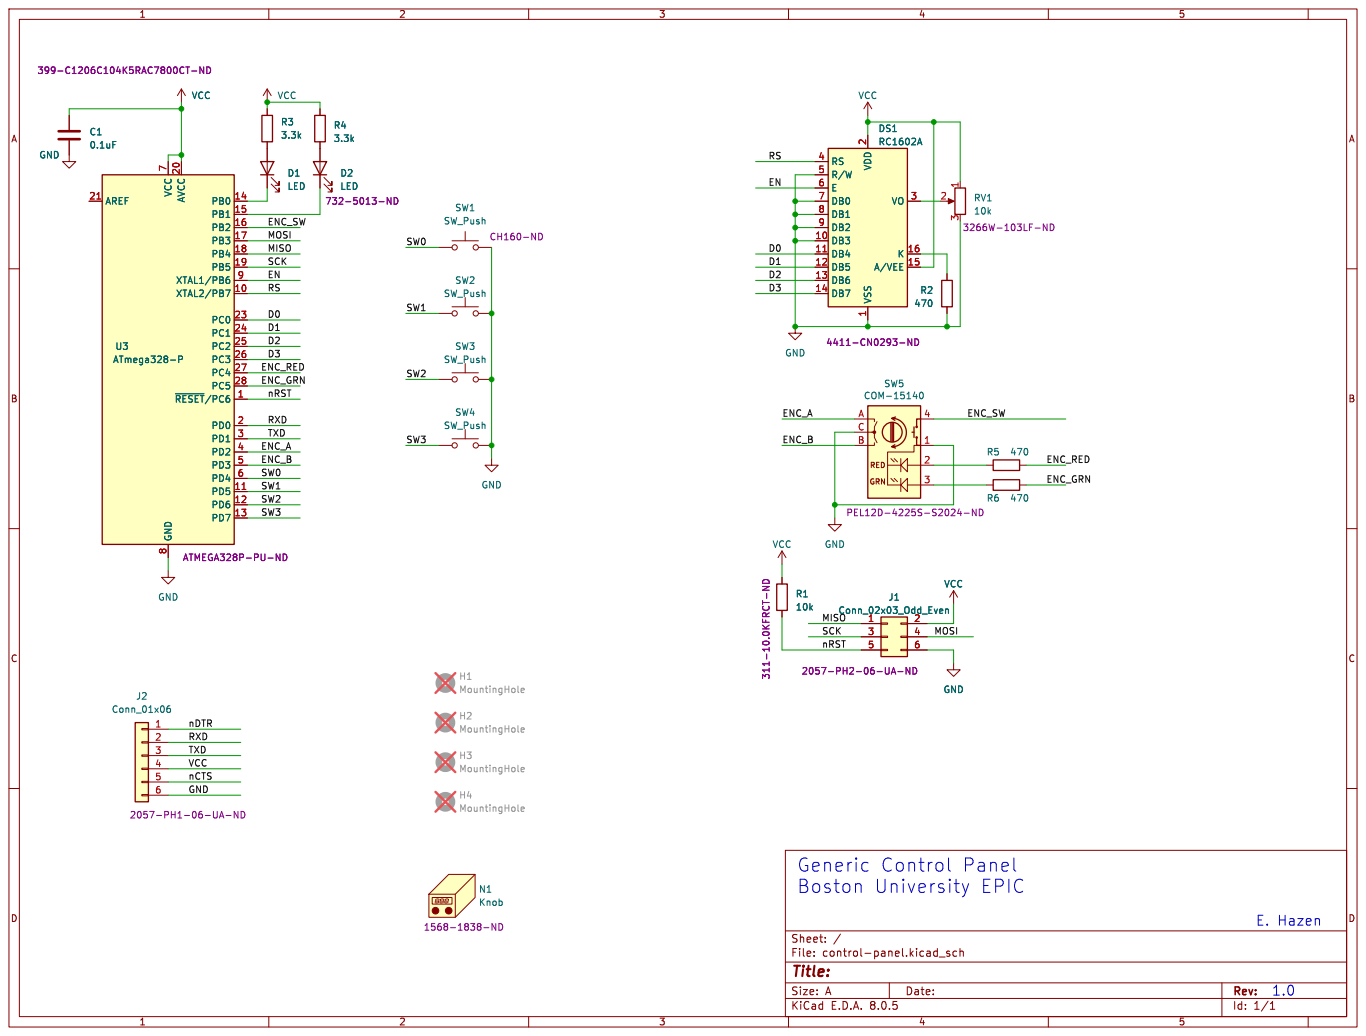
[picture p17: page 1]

H3 MountingHole H2 MountingHole H1 MountingHole H4 MountingHole N1Knob

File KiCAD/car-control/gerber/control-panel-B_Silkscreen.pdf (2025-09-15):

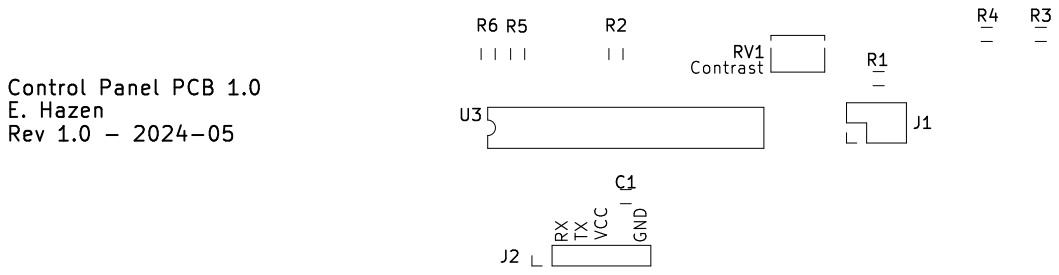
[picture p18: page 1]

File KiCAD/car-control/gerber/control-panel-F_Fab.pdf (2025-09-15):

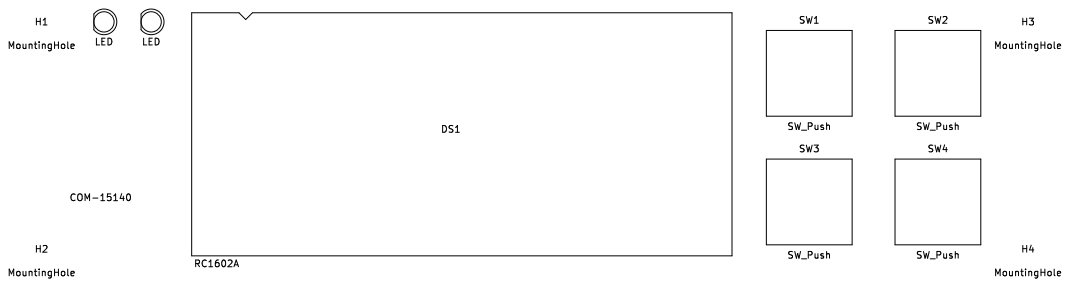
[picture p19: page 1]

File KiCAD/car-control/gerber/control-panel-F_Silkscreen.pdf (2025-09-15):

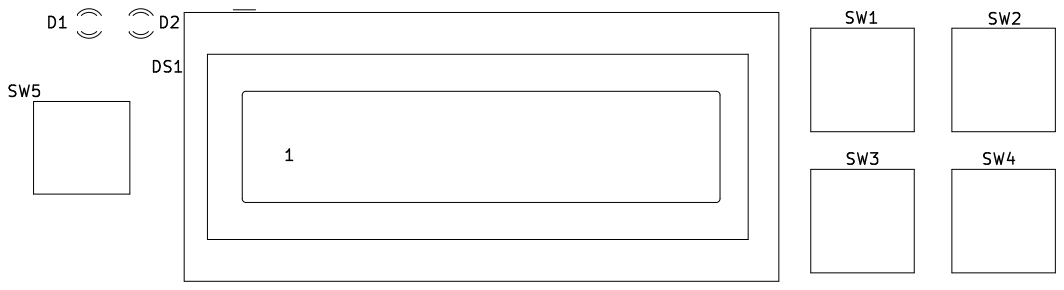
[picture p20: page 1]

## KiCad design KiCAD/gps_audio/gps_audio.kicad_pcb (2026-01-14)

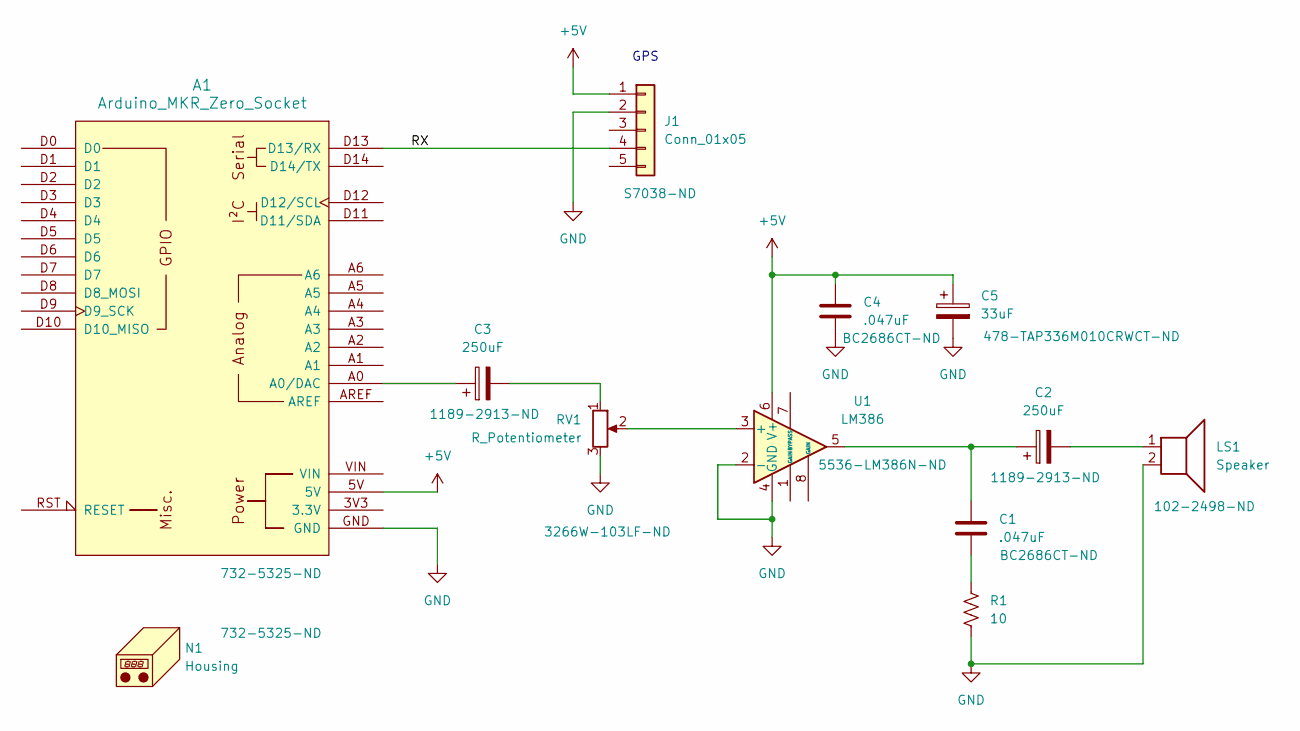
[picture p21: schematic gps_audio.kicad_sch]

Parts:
A1: Arduino_MKR_Zero_Socket
C1, C4: .047uF; C_Disc_D7.0mm_W2.5mm_P5.00mm
C2, C3: 250uF; CP_Radial_D6.3mm_P2.50mm
C5: 33uF; CP_Radial_Tantal_D4.5mm_P5.00mm
J1: Conn_01x05; gps_module
LS1: Speaker; CVS-1508_CUD
N1: Housing
R1: 10; R_Axial_DIN0207_L6.3mm_D2.5mm_P10.16mm_Horizontal
RV1: R_Potentiometer; Potentiometer_Bourns_3266W_Vertical
U1: LM386; DIP-8_W7.62mm

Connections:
+5V: A1.5V, C4.1, C5.1, J1.1, U1.6 (V+)
/RX: A1.D13 (D13/RX), J1.4
GND: A1.GND, C4.2, C5.2, J1.2, LS1.2, R1.2, RV1.3, U1.2 (-), U1.4 (GND)
unnamed: A1.A0 (A0/DAC), C3.1
unnamed: C1.1, C2.1, U1.5
unnamed: C1.2, R1.1
unnamed: C2.2, LS1.1
unnamed: C3.2, RV1.1
unnamed: RV1.2, U1.3 (+)

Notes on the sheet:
GPS

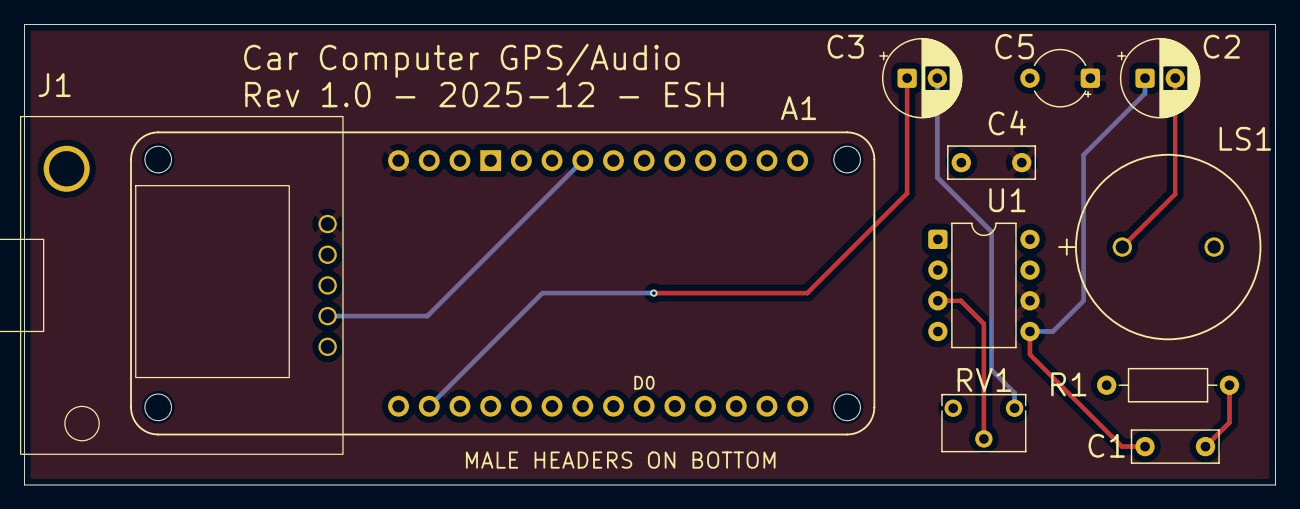
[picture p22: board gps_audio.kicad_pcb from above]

Board: 2 copper layers, 103.5 x 38.1 mm, 11 parts (0 on the bottom side), 9 nets.

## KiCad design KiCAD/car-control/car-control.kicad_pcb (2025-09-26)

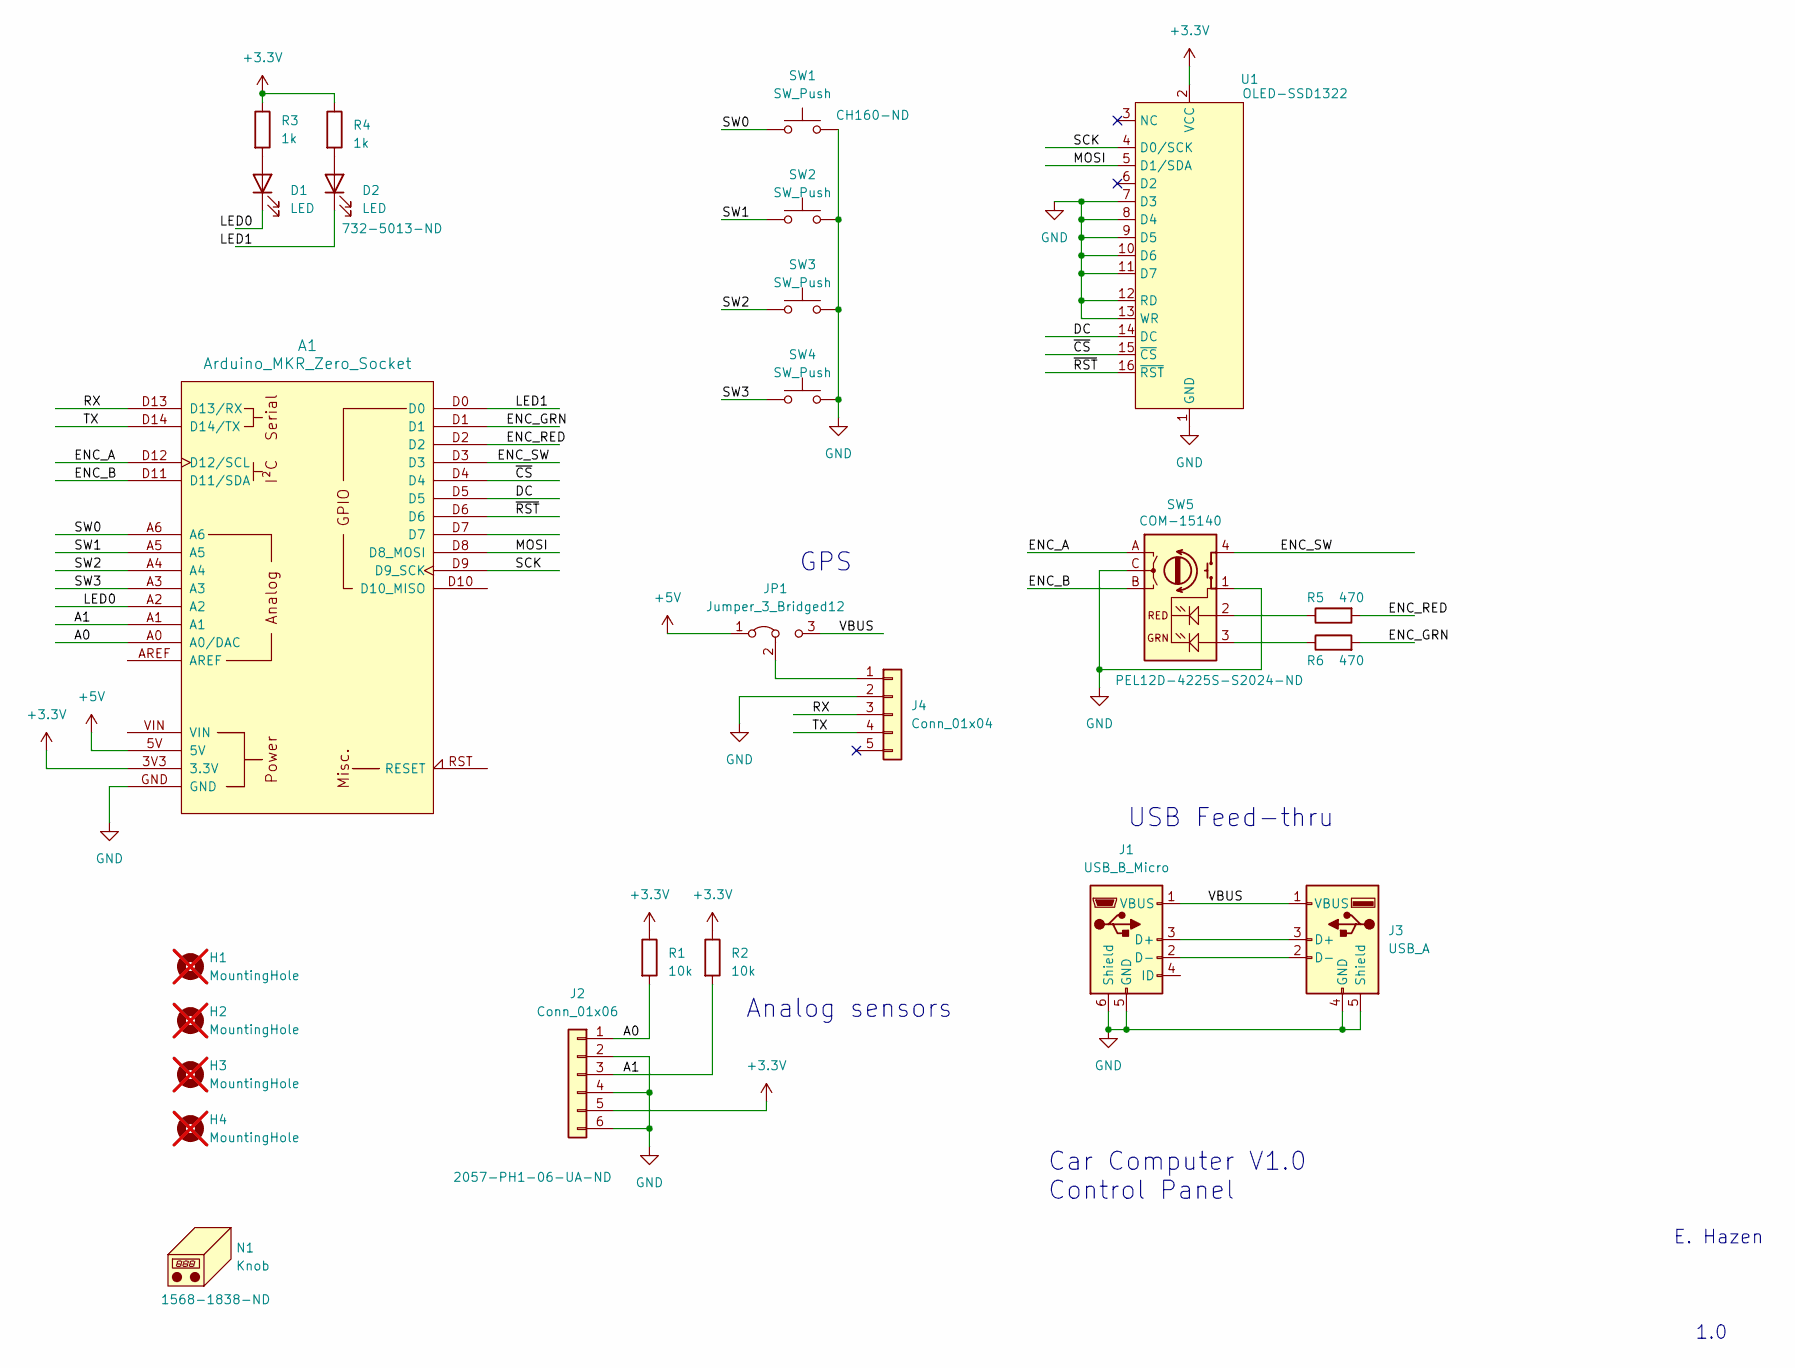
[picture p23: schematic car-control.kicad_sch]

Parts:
A1: Arduino_MKR_Zero_Socket
D1, D2: LED; LED_D3.0mm
H1, H2, H3, H4: MountingHole; mtg_hole_4-40; not fitted
J1: USB_B_Micro; CONN_USB3131-30-0230-A_GCT
J2: Conn_01x06; PinHeader_1x06_P2.54mm_Vertical
J3: USB_A; CONN_USB-A-S-VT_ADM
J4: Conn_01x04; PinSocket_1x05_P2.54mm_Vertical
JP1: Jumper_3_Bridged12; PinHeader_1x03_P2.54mm_Vertical
N1: Knob
R1, R2: 10k; R_1206_3216Metric_Pad1.30x1.75mm_HandSolder
R3, R4: 1k; R_1206_3216Metric_Pad1.30x1.75mm_HandSolder
R5, R6: 470; R_1206_3216Metric_Pad1.30x1.75mm_HandSolder
SW1, SW2, SW3, SW4: SW_Push; SW_Cherry_MX_1.00u_PCB
SW5: COM-15140; rotary-RG-3D
U1: OLED-SSD1322; OLED_312_16pin

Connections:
+3.3V: A1.3V3 (3.3V), J2.5, R1.1, R2.1, R3.1, R4.1, U1.2 (VCC)
+5V: A1.5V, JP1.1 (A)
/A0: A1.A0 (A0/DAC), J2.1, R1.2
/A1: A1.A1, J2.3, R2.2
/DC: A1.D5, U1.14 (DC)
/ENC_A: A1.D12 (D12/SCL), SW5.A
/ENC_B: A1.D11 (D11/SDA), SW5.B
/ENC_GRN: A1.D1, R6.2
/ENC_RED: A1.D2, R5.2
/ENC_SW: A1.D3, SW5.4 (S1)
/LED0: A1.A2, D1.1 (K)
/LED1: A1.D0, D2.1 (K)
/MOSI: A1.D8 (D8_MOSI), U1.5 (D1/SDA)
/RX: A1.D13 (D13/RX), J4.3
/SCK: A1.D9 (D9_SCK), U1.4 (D0/SCK)
/SW0: A1.A6, SW1.1
/SW1: A1.A5, SW2.1
/SW2: A1.A4, SW3.1
/SW3: A1.A3, SW4.1
/TX: A1.D14 (D14/TX), J4.4
/VBUS: J1.1 (VBUS), J3.1 (VBUS), JP1.3 (B)
/~CS: A1.D4, U1.15 (~CS)
/~RST: A1.D6, U1.16 (~RST)
GND: A1.GND, J1.5 (GND), J1.6 (Shield), J2.2, J2.4, J2.6, J3.4 (GND), J3.5 (Shield), J4.2, SW1.2, SW2.2, SW3.2, SW4.2, SW5.1 (S2), SW5.C, U1.1 (GND), U1.7 (D3), U1.8 (D4), U1.9 (D5), U1.10 (D6), U1.11 (D7), U1.12 (RD), U1.13 (WR)
unnamed: D1.2 (A), R3.2
unnamed: D2.2 (A), R4.2
unnamed: J1.3 (D+), J3.3 (D+)
unnamed: J1.2 (D-), J3.2 (D-)
unnamed: J4.1, JP1.2 (C)
unnamed: R6.1, SW5.3 (GREEN)
unnamed: R5.1, SW5.2 (RED)

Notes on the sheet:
E. Hazen
GPS
USB Feed-thru
Car Computer V1.0 Control Panel
1.0
Analog sensors

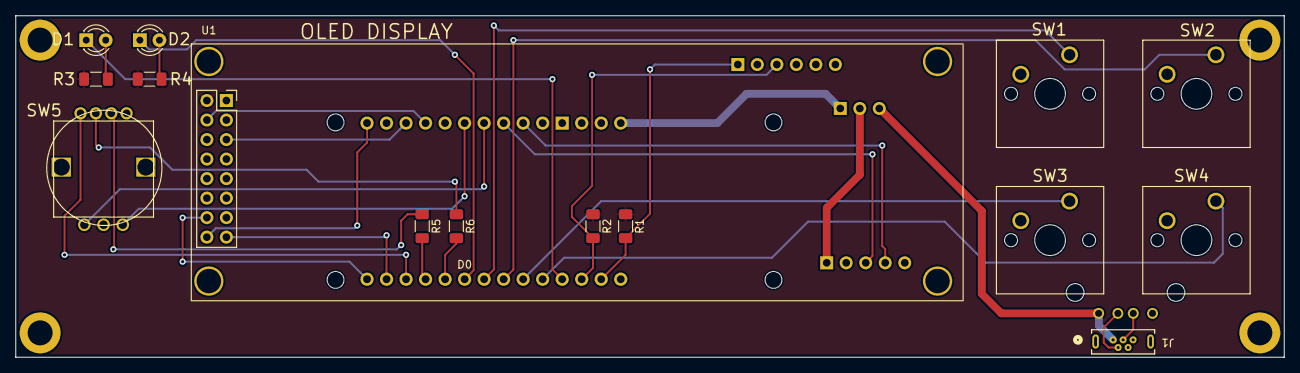
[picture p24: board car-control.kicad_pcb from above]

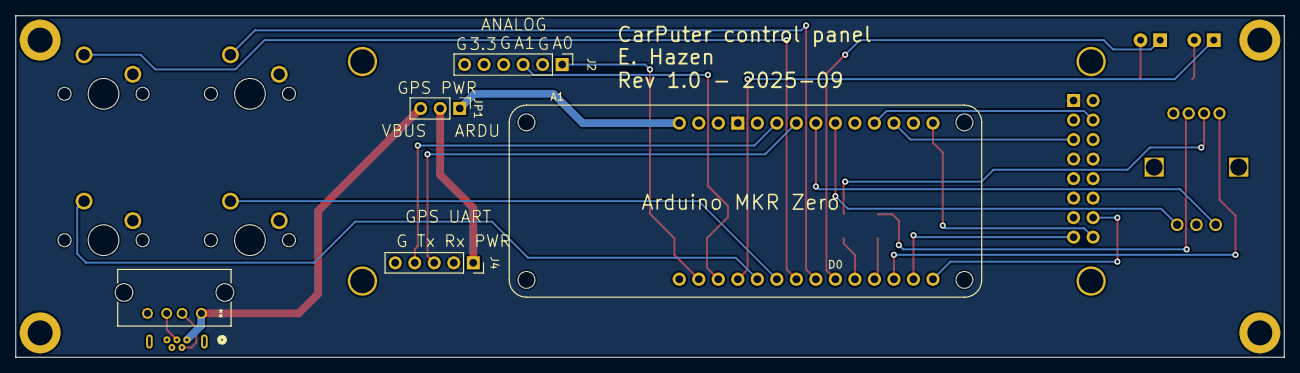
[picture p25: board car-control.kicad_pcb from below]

Board: 2 copper layers, 165.1 x 44.5 mm, 24 parts (5 on the bottom side), 31 nets.

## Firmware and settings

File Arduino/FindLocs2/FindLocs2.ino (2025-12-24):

//
// Second generation display code
//
// read GPS lat/long
// display GMT time and nearest places
//
// use files:
//   config.csv    - configuration file, specifies names of place groups
//   grid.csv      - one line of grid spacing/range info
// for each place group
//   <name>.csv    - places annotated with grid coordinates
//   <name>.idx    - 256x256 array of 32-bit binary integers
//                   with offsets to start of each grid cell
// config file, e.g:
//
//   Type,File,Name
//   1,TOWN,"Towns"
//   2,AIRPORT,"Airports"
//   3,DINER,"Diners"
//
// so will expect to find files:  TOWN.CSV, TOWN.IDX, AIRPORT.CSV, AIRPORT.IDX etc
//

// #define DEBUG
// #define DEBUGXX 
// #define UART_DEBUG

#define USE_OLED
#define USE_GPS
#define USE_TIMER

// #define NO_INSERT
#define DO_INSERT

#include <math.h>
// #include <SPI.h>
#include <SD.h>
#include <string.h>

#ifdef USE_TIMER
#include <Arduino.h>
#include "Adafruit_ZeroTimer.h"
#endif

#ifdef USE_OLED
#include "oled.h"
#else
#define USE_LINES 4
#endif

#include "distance_miles.h"
#include "places.h"
#include "parse_csv.h"

#include "encoder.h"

#ifdef USE_TIMER
Adafruit_ZeroTimer zerotimer = Adafruit_ZeroTimer(3);

void TC3_Handler() {
  Adafruit_ZeroTimer::timerHandler(3);
}

// the timer callback
volatile bool togglepin = false;
void TimerCallback0(void)
{
  encoder->tick();
}

#endif


// ---- hardwired (ugh) input file names ----
#define CONFIG_FILE "CONFIG.CSV"
#define GRID_FILE "GRID.CSV"

// maximum number of groups we can handle
#define MAX_GROUPS 5
// length of an 8 char filename with null terminator
#define MAX_FILE 9
// maximum length of group name
#define G_MAX_NAME 10
typedef struct {
  byte type;
  char file[MAX_FILE];
  char name[G_MAX_NAME];
} a_group;

a_group groups[MAX_GROUPS];
static int ngroups;

int grp = 0;			// current group


const int chipSelect = SDCARD_SS_PIN;

static char buff[80];
static char prnt[128];

static char* tokn[10];
#define MAXT (sizeof(tokn)/sizeof(tokn[0]))

File fc;			// config file pointer
File fg;			// grid file pointer

File fp[MAX_GROUPS];		// places file pointers
File fpi[MAX_GROUPS];		// index file pointers

// grid specifications from file
int numLat;
float latMin;
float latMax;
float latStep;
int numLon;
float lonMin;
float lonMax;
float lonStep;

char gpsStatus = 'X';			// last GGA message status
int gpsNumSat = 0;			// last GGA messag number of sats

static a_place tempPlace;

// array of up to nearby locations from our grid cell
// and neighboring ones
a_loc sortedLocs[10];
#define MAXLOC (sizeof(sortedLocs)/sizeof(a_loc))
static int numLoc;		/* pointer to last occupied in sortedLocs */

#ifdef USE_OLED
void oled_print( int line, const char *str) {
  if( line < USE_LINES) {
    draw_text( oledBuf, str, 1, (line+1) * LINE_SPC, 15);
    send_buffer_to_OLED( oledBuf, 0, 0);
  }
}
#endif



#ifdef USE_GPS
//
// try to get a GPS fix
// return pointer to GMT time on success, NULL on error
// if location not available, set lat = lon = -1
//
// blocks until receive a GPS message $GPRMC on Serial1
//
char* GPS_fix( float *flat, float *flon) {

  static char tyme[40];

  char gps[80];
  char *str;
  char *p;
  char *gmt;
  char *date;
  char *stat;
  char *lat;
  char *ns;
  char *lon;
  char *ew;

  char *ret = NULL;

  while( 1) {

    

    if( Serial1.available()) {
      int nc = Serial1.readBytesUntil( '\n', gps, sizeof(gps)-1);
      gps[nc] = '\0';

      if( !strncasecmp( gps, "$GPGGA", 6)) {

	str = gps;
#ifdef UART_DEBUG
	Serial.println( gps);
#endif
	p = strsep( &str, ",");	// 0 skip msg
	p = strsep( &str, ",");	// 1 skip time
	p = strsep( &str, ",");	// 2 skip lat
	p = strsep( &str, ",");	// 3 skip ns
	p = strsep( &str, ",");	// 4 skip lon
	p = strsep( &str, ",");	// 5 skip ew
	ew = strsep( &str, ",");// 6 position fix status
	ns = strsep( &str, ",");// 7 num sats

	gpsStatus = ew[0];
	gpsNumSat = atoi( ns);
      }

      if( !strncasecmp( gps, "$GPRMC", 6)) {
	// parse and display stuff
	str = gps;
	p = strsep( &str, ",");	// skip over header   0
	gmt = strsep( &str, ",");	// get UTC time       1
	stat = strsep( &str, ","); // get status        2
	lat = strsep( &str, ","); // get latitude       3
	ns = strsep( &str, ","); // n/s                 4
	lon = strsep( &str, ","); // get longitude      5
	ew = strsep( &str, ","); // e/w                 6
	p = strsep( &str, ","); // skip                 7
	p = strsep( &str, ","); // skip                 8
	date = strsep( &str, ","); // date              9

#ifdef UART_DEBUG	
	if( strlen(gps) < 25 || strlen(lat) < 3 )
	  Serial.println( gps);
#endif

	if( strlen(gmt) > 3) {
	  strncpy( tyme, gmt, sizeof(tyme));
	  ret = tyme;
	}

	*flat = *flon = -1.0;	// default return values

	  if( strlen(lat) > 5 && strlen(lon) > 5) {	// got a fix

	  // convert lat/lon
	  *flat = conv_ll( lat);
	  if( toupper(*ns) == 'S')
	    *flat = -*flat;
	  *flon = conv_ll( lon);
	  if( toupper(*ew) == 'W')
	    *flon = -*flon;
	} // if( got a fix)

	return ret;

      } // if( $GPRMC)
    }
  } // while(1)
}

// convert NEMA lat/long to decimal degrees
// format is:  dddmm.ffff
//    ddd is integer degrees (1-3 digits)
//     mm is integer minutes
//   ffff is fractional minutes
float conv_ll( char *str) {
  static float minu;
  static float degr;
  char *dp = strchr( str, '.');  // point to decimal
  if( dp == NULL)
    return( 0.0);
  dp -= 2;              // point to minutes
  minu = atof(dp);      // convert floating minutes
  *dp = '\0';           // terminate degrees
  degr = atof( str);    // convert float degrees
  degr += minu / 60.0;  // add minutes
  return degr;          // return result
}

#endif

void flush() {
#ifdef USE_GPS
  while( Serial1.available())
    Serial1.read();
#endif
}



#ifdef DEBUGXX
// debug:  dump a a_loc list
void dump_list( a_loc *list, int nlist) {
  snprintf( prnt, sizeof(prnt), "dump_list( size=%d)\n", nlist);
  Serial.print(prnt);
  if( nlist) {
    for( int i=0; i<nlist; i++) {
      snprintf( prnt, sizeof(prnt), "  %d 0x%08x, %f\n", i, list[i].offset, list[i].distance);
      Serial.print( prnt);
    }
  }
}
#endif  

//
// process a grid square
//
//int process_grid_at( float lat, float lon, int latGrid, int lonGrid, a_loc* list, int nlist, int maxlist) {
int process_grid_at( float lat, float lon, int latGrid, int lonGrid, void* vlist, int nlist, int maxlist) {

#ifdef DEBUGXX
  snprintf( prnt, sizeof(prnt), "pg() %f %f %d %d 0x%x %d %d\n",
	    lat, lon, latGrid, lonGrid, (int)vlist, nlist, maxlist);
  Serial.print( prnt);
#endif  

  // why ??? GCC / Arduino bug prevents using a_loc* in arg list
  a_loc *list;
  list = (a_loc *)vlist;

  uint32_t offset;
  a_loc loc;
  int numThisGrid = 0;

  // check for out of range
  if( latGrid < 0 || lonGrid < 0 || lonGrid > 255 || latGrid > 255)
    return 0;

  uint32_t posn = ((latGrid << 8) | lonGrid) * sizeof( uint32_t);
  fpi[grp].seek( posn);
  fpi[grp].read( &offset, sizeof(offset));

#ifdef DEBUGXX
    snprintf( prnt, sizeof(prnt), "Seek %ld\n", offset);
    Serial.print(prnt);
#endif

  if( offset != 0xffffffff) {

    fp[grp].seek( offset);
    uint32_t offs0 = offset;
    int insPt;

#ifdef DEBUGXX
    snprintf( prnt, sizeof(prnt), "Seeked %ld\n", offset);
    Serial.print(prnt);
#endif

    // read until EOF or grid changes
    
    while( int n = fp[grp].readBytesUntil( 0xa, buff, sizeof(buff))) {
      buff[n] = '\0';
      offset = fp[grp].position();
      if( csv_to_place( &tempPlace, buff)) {
#ifdef USE_OLED
	oled_print(0,"FAIL ON CSV");
#endif
	while(1) ;
      }

#ifdef DEBUGXX
      snprintf( prnt, sizeof(prnt), "Grid %d, %d\n", tempPlace.lat_grid, tempPlace.lon_grid);
      Serial.print( prnt);
#endif

      if( tempPlace.lat_grid == latGrid && tempPlace.lon_grid == lonGrid) {
	++numThisGrid;
	loc.offset = offs0;
	loc.distance = distance_miles( lat, lon, tempPlace.lat, tempPlace.lon);

#ifdef NO_INSERT
	// for debug, just fill the list
	if( nlist < maxlist)
	  list[nlist++] = loc;
#endif

#ifdef DO_INSERT
	// insert in list maintaining order
	if( nlist == 0) {		/* empty list case */
	  list[nlist++] = loc;
	} else { // list not empty, occupied from 0..nlist-1

	  for( insPt=0; insPt<nlist; insPt++) { /* else find where it fits */
	    if( loc.distance <= list[insPt].distance) { /* insert here */
	      // check for end
	      if( insPt != maxlist-1) { // only if not at end
		// shift all including list[insPt] to right
		for( int j=maxlist-2; j>=insPt; j--)
		  list[j+1] = list[j];
	      }
	      // insert item
	      list[insPt] = loc;
	      if( nlist < maxlist-1)
		++nlist;
	      break;
	    }
	  }
	}
#endif
	offs0 = offset;
      } else {			// if( same grid)
	break;			// break loop if not
      }
    }
  }
#ifdef DEBUGXX
  snprintf( prnt, sizeof(prnt), "numThisGrid=%d\n", numThisGrid);
  Serial.print(prnt);
  snprintf( prnt, sizeof(prnt), "read %d locations\n", nlist);
  Serial.print(prnt);
#endif
  return nlist;
}


static int i, j, k, n;
static int ng;

void setup() {

#ifdef UART_DEBUG
  Serial.begin(9600);
  while (!Serial) {
    ;
  }
#endif

  encoder_setup();

#ifdef USE_TIMER
#ifdef UART_DEBUG
  Serial.println("Setting up timer");
#endif
  delay(1000);

  // Set up the flexible divider/compare
  uint16_t divider  = 4;
  uint16_t compare = (48000000/4)/250.0;
  tc_clock_prescaler prescaler = TC_CLOCK_PRESCALER_DIV4;

  zerotimer.enable(false);
  zerotimer.configure(prescaler,       // prescaler
          TC_COUNTER_SIZE_16BIT,       // bit width of timer/counter
          TC_WAVE_GENERATION_MATCH_PWM // frequency or PWM mode
          );

  zerotimer.setCompare(0, compare);
  zerotimer.setCallback(true, TC_CALLBACK_CC_CHANNEL0, TimerCallback0);
  zerotimer.enable(true);
#endif  

#ifdef USE_OLED
  SSD1322_HW_Init();
  SSD1322_API_init();
  select_font( &FreeMono9pt7b);
#endif

#ifdef DEBUG
  Serial.print("Initializing SD card...");
#endif

#ifdef USE_GPS  
  Serial1.begin(9600);
  flush();
#endif

  pinMode( LED_BUILTIN, OUTPUT);
#ifdef USE_OLED
  fill_buffer( oledBuf, 0);		// clear screen
  oled_print( 0, "FindLocs 2.0");
  delay(1000);
#endif

  interrupts();

  // see if the card is present and can be initialized:
  if (!SD.begin(chipSelect)) {

#ifdef USE_OLED
    fill_buffer( oledBuf, 0);		// clear screen
    oled_print( 1, "uSD FAIL");
#endif    
#ifdef DEBUG
    Serial.println("Card failed, or not present");
#endif
    while (1);
  }
#ifdef USE_OLED
  fill_buffer( oledBuf, 0);		// clear screen
  oled_print( 0, "uSD OK");
#endif
#ifdef DEBUG
  Serial.println("card initialized.");
#endif

#ifdef DEBUG
  File root = SD.open("/");
  printDirectory(root, 0);
#endif
  
  // read the config, find number of groups
  fc = SD.open( CONFIG_FILE);
  if( !fc) {
#ifdef USE_OLED
    oled_print( 0, "No config");
#endif
    while(1);
  }

#ifdef DEBUG
  Serial.println("config open");
#endif  
    
  // read and skip header
  fc.readBytesUntil( 0xa, buff, sizeof(buff));
#ifdef USE_OLED
  fill_buffer( oledBuf, 0);		// clear screen
#endif
  ngroups = 0;
  while( fc.readBytesUntil( 0xa, buff, sizeof(buff)) && ngroups < MAX_GROUPS) {
#ifdef DEBUG
    Serial.println( buff);
#endif    
    int ng = parse_csv_line(buff, tokn, MAXT);
    groups[ngroups].type = atoi( tokn[0]);
    strncpy( groups[ngroups].file, tokn[1], sizeof(groups[0].file));
    strncpy( groups[ngroups].name, tokn[2], sizeof(groups[0].name));
    if( ngroups < USE_LINES) {
      snprintf( prnt, sizeof(prnt), "%d %s %s", ngroups, groups[ngroups].file, groups[ngroups].name);
#ifdef USE_OLED
      oled_print( ngroups, prnt);
#endif
      ++ngroups;
    }
  }

  // read grid file (2 lines, with grid specs)
  fg = SD.open( GRID_FILE);
  if( !fg) {
    fill_buffer( oledBuf, 0);		// clear screen
    oled_print( 1, "Grid file error");
    while(1) ;
  }
    
  n = fg.readBytesUntil( 0xa, buff, sizeof(buff));
  n = fg.readBytesUntil( 0xa, buff, sizeof(buff));
  buff[n] = '\0';
  
  ng = parse_csv_line(buff, tokn, MAXT);
  if( ng != 8) {
#ifdef USE_OLED
    fill_buffer( oledBuf, 0);		// clear screen
    oled_print( 1, "Grid data error");
#endif    
#ifdef DEBUG
    Serial.print( "Error processing grid data:");
    Serial.println( buff);
#endif
    while(1) ;
  }

  // get grid specifications from file
  numLat = atoi( tokn[0]);
  latMin = atof( tokn[1]);
  latMax = atof( tokn[2]);
  latStep = atof( tokn[3]);
  numLon = atoi( tokn[4]);
  lonMin = atof( tokn[5]);
  lonMax = atof( tokn[6]);
  lonStep = atof( tokn[7]);

  delay(500);

#ifdef DEBUG
  Serial.print("ngroups = ");
  Serial.println( ngroups);
#endif

  // open CSV and IDX files
  for( i=0; i<ngroups; i++) {
    snprintf( buff, sizeof(buff), "%s.CSV", groups[i].file);
    fp[i] = SD.open( buff);
    snprintf( buff, sizeof(buff), "%s.IDX", groups[i].file);
    fpi[i] = SD.open( buff);
  
    if( !fp[i] || !fpi[i]) {
      snprintf( prnt, sizeof(prnt), "Missing %s file", groups[i].file);
#ifdef USE_OLED
      fill_buffer( oledBuf, 0);		// clear screen
      oled_print( 0, prnt);
#endif    
#ifdef DEBUG
      Serial.println( prnt);
#endif
      while(1) ;
    }
  }

} // setup()

int fake_time = 0;
#ifndef USE_GPS
char gpsFake[32];
#endif

void loop() {

  float floatLat;
  float floatLon;

  int update_time = 0;
  const char *gpsTime;

  static int pos = 0;
  int newPos = encoder->getPosition();
  if (pos != newPos)
    pos = newPos;

  grp = newPos % ngroups;

#ifdef USE_GPS
  gpsTime = GPS_fix( &floatLat, &floatLon);
#else
  //floatLat = 42.0 + (float)random(100)/100;
  //  floatLon = -71.8 + (float)random(100)/100;
  floatLon = -85.0 + (float)random(10) + (float)random(100)/100.0;
  floatLat = 35 + (float)random(5)  + (float)random(100)/100.0;
  fake_time++;
  snprintf( gpsFake, sizeof(gpsFake), "T%d %d", fake_time, newPos);
  gpsTime = gpsFake;
  delay(1000);
#endif  

  // check GPS status
  if( gpsTime == NULL) { 		// no GPS at all
#ifdef DEBUG
    Serial.println("NO GPS");
#endif
#ifdef USE_OLED
  fill_buffer( oledBuf, 0);		// clear screen
  oled_print( 0, "NO GPS");
#endif    
  } else if( floatLat < 0) {	// no location
#ifdef DEBUG
    Serial.println("NO LOC");
#endif
#ifdef USE_OLED
  fill_buffer( oledBuf, 0);		// clear screen
  oled_print( 0, "NO LOC");
  oled_print( USE_LINES-1, gpsTime);
#endif    
  } else {

//#ifndef USE_GPS
//    floatLat = 42.1111;
//    floatLon = -72.3333;
//#endif    

    // calculate our grid location from "GPS"
    int latGrid = (floatLat - latMin) / latStep;
    int lonGrid = (floatLon - lonMin) / lonStep;

    int oldLatGrid, oldLonGrid;

    // calculate remainder (offset within grid cell)
    float lat_rem = floatLat - (latMin + (float)latGrid * latStep);
    float lon_rem = floatLon - (lonMin + (float)lonGrid * lonStep);

    // calculate which direction to look in neighbor cells
    int latNeighbor = lat_rem > 0.5 ? latGrid+1 : latGrid-1;
    int lonNeighbor = lon_rem > 0.5 ? lonGrid+1 : lonGrid-1;

#ifdef DEBUG
    snprintf( prnt, sizeof(prnt), "Grid: Lat %d %f .. %f step %f \n", numLat, latMin, latMax, latStep);
    Serial.print(prnt);
    snprintf( prnt, sizeof(prnt), "Grid: Lon %d %f .. %f step %f \n", numLon, lonMin, lonMax, lonStep);
    Serial.print(prnt);
    snprintf( prnt, sizeof(prnt), "Grid for lat %f lon %f is (%d, %d)\n", floatLat, floatLon, latGrid, lonGrid);
    Serial.print(prnt);
    snprintf( prnt, sizeof(prnt), "Neighbors: %d, %d\n", latNeighbor, lonNeighbor);
    Serial.print(prnt);
#endif
  
    // process 4 neighboring grids
    numLoc = 0;
    numLoc = process_grid_at( floatLat, floatLon, latGrid, lonGrid, sortedLocs, numLoc, MAXLOC);
#ifdef DEBUG
    snprintf( prnt, sizeof(prnt), "process.. returned %d\n", numLoc);
    Serial.print(prnt);
#endif    

    numLoc = process_grid_at( floatLat, floatLon, latNeighbor, lonGrid, sortedLocs, numLoc, MAXLOC);
    numLoc = process_grid_at( floatLat, floatLon, latGrid, lonNeighbor, sortedLocs, numLoc, MAXLOC);
    numLoc = process_grid_at( floatLat, floatLon, latNeighbor, lonNeighbor, sortedLocs, numLoc, MAXLOC);

    // update only if we moved
    if( 1) {
      //    if( latGrid != oldLatGrid || lonGrid != oldLonGrid) {

      oldLatGrid = latGrid;
      oldLonGrid = lonGrid;
      
#ifdef USE_OLED
      fill_buffer( oledBuf, 0);		// clear screen
#endif

      for( int i=0; i<numLoc; i++) {
#ifdef DEBUGXXX
	snprintf( prnt, sizeof(prnt), "offset = %d  dist = %f : ", sortedLocs[i].offset, sortedLocs[i].distance);
	Serial.print( prnt);
#endif
	fp[grp].seek( sortedLocs[i].offset);
	n = fp[grp].readBytesUntil( 0xa, buff, sizeof(buff));
	buff[n] = '\0';
	csv_to_place( &tempPlace, buff);
#ifdef DEBUGXXX
	dump_place( &tempPlace);
#endif
#ifdef USE_OLED
	place_to_short( &tempPlace, buff, 40, sortedLocs[i].distance);
	if( i < 3)
	  oled_print( i, buff);
#endif    
      } // loop over nearest places
      // status line at bottom
#ifdef USE_OLED
      snprintf( buff, sizeof(buff), "%6.6s %c %d %d", gpsTime, gpsStatus, gpsNumSat, newPos);
      select_font( &FreeMono12pt7b);
      //    draw_text( oledBuf, str, 1, (line+1) * LINE_SPC, 15);
      draw_text( oledBuf, buff, 0, 63, 8);
      send_buffer_to_OLED( oledBuf, 0, 0);
      select_font( &FreeMono9pt7b);
#endif
    }

  } // else got a fix

} // loop()








void printDirectory(File dir, int numTabs) {

  while (true) {
    File entry =  dir.openNextFile();
    if (! entry) {
      // no more files
      break;
    }
    for (uint8_t i = 0; i < numTabs; i++) {
      Serial.print('\t');
    }
    Serial.print(entry.name());
    if (entry.isDirectory()) {
      Serial.println("/");
      printDirectory(entry, numTabs + 1);
    } else {
      // files have sizes, directories do not
      Serial.print("\t\t");
      Serial.println(entry.size(), DEC);
    }
    entry.close();
  }
}

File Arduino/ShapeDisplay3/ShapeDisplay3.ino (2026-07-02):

//
// Starting on V3.0
//
// Working display code
// Look for GPS messages
// Looup Lat/Lon using hardwired file names STUFF.DAT .VRT .PRT .REE
// Display highest 3 priorities (norm. Neighborhood, City, County, State) on display
//
// Play "test.wav" sound for new locations
//

#include <AudioZero.h>

#include <math.h>
#include <SD.h>
#include <string.h>
#include <avr/dtostrf.h>
#include <stdint.h>
#include <stddef.h>

#include "oled.h"
#include "shape.h"
#include "filetree.h"
#include "replac.c"

#define USE_GPS
// #define RAND_POS

// lookup timezone (slow!)
#define USE_ZONE

#define USE_OLED

// #define DEBUG
// #define USE_SERIAL

// maximum priority data we can handle
#define MAX_PRIO 8
uint32_t prio_item[MAX_PRIO];	// offsets in datafile for current search priority items
uint32_t prio_hash, prio_new_hash;		// hash of last set

int point_in_part_file( File fv, int n, coord_t x, coord_t y);
void search_tree( coord_t lat, coord_t lon, long offset, File ft, File fd, File fv, File fa, int flag);
uint32_t hash_u32_list(const uint32_t *values, size_t count);

const int chipSelect = SDCARD_SS_PIN;

char prnt[100];
char slat[12];
char slon[12];
char tzon = '?';		// set to E, C, M, P
const char* zonz = "ECMP";

File ft;
File fd;
File fv;
File fa;

File zt;
File zd;
File zv;
File za;


char gpsStatus = 'X';			// last GGA message status
int gpsNumSat = 0;			// last GGA messag number of sats

long start;

//
// try to get a GPS fix
// return pointer to GMT time on success, NULL on error
// if location not available, set lat = lon = -1
// if GPS times out, return NULL
// 
// wait 5s to receive a GPS message $GPRMC on Serial1
//

// global to keep track
static char tyme[40];
char gps[80];
char *gps_str;
char *gps_p;
char *gmt;
char *date;
char *stat;
char *lat;
char *ns;
char *lon;
char *ew;
char *ret;

#ifdef USE_GPS

char* GPS_fix( float *flat, float *flon) {
  ret = NULL;
  start = millis();
  
  while( (millis() - start) < 5000) {

    if( Serial1.available()) {
      int nc = Serial1.readBytesUntil( '\n', gps, sizeof(gps)-1);
      gps[nc] = '\0';

      if( !strncasecmp( gps, "$GPGGA", 6)) {

	gps_str = gps;
#ifdef USE_SERIAL
	Serial.println( gps);
#endif
	gps_p = strsep( &gps_str, ",");	// 0 skip msg
	gps_p = strsep( &gps_str, ",");	// 1 skip time
	gps_p = strsep( &gps_str, ",");	// 2 skip lat
	gps_p = strsep( &gps_str, ",");	// 3 skip ns
	gps_p = strsep( &gps_str, ",");	// 4 skip lon
	gps_p = strsep( &gps_str, ",");	// 5 skip ew
	ew = strsep( &gps_str, ",");// 6 position fix status
	ns = strsep( &gps_str, ",");// 7 num sats

	gpsStatus = ew[0];
	gpsNumSat = atoi( ns);
      }

      if( !strncasecmp( gps, "$GPRMC", 6)) {
#ifdef USE_SERIAL
	if( strlen(gps) < 25 || strlen(lat) < 3 )
	  Serial.println( gps);
#endif

	// parse and display stuff
	gps_str = gps;
	gps_p = strsep( &gps_str, ",");	// skip over header   0
	gmt = strsep( &gps_str, ",");	// get UTC time       1
	stat = strsep( &gps_str, ","); // get status        2
	lat = strsep( &gps_str, ","); // get latitude       3
	ns = strsep( &gps_str, ","); // n/s                 4
	lon = strsep( &gps_str, ","); // get longitude      5
	ew = strsep( &gps_str, ","); // e/w                 6
	gps_p = strsep( &gps_str, ","); // skip                 7
	gps_p = strsep( &gps_str, ","); // skip                 8
	date = strsep( &gps_str, ","); // date              9 format ddmmyy

	if( strlen(gmt) > 3) {
	  strncpy( tyme, gmt, sizeof(tyme));
	  ret = tyme;
	} else {
	  strcpy( tyme, "NONE");
	  ret = tyme;
	}

	*flat = *flon = -1.0;	// default return values

	  if( strlen(lat) > 5 && strlen(lon) > 5) {	// got a fix

	  // convert lat/lon
	  *flat = conv_ll( lat);
	  if( toupper(*ns) == 'S')
	    *flat = -*flat;
	  *flon = conv_ll( lon);
	  if( toupper(*ew) == 'W')
	    *flon = -*flon;
	} // if( got a fix)

	return ret;

      } // if( $GPRMC)
    }
  } // while(1)
  return ret;
}

// convert NEMA lat/long to decimal degrees
// format is:  dddmm.ffff
//    ddd is integer degrees (1-3 digits)
//     mm is integer minutes
//   ffff is fractional minutes
float conv_ll( char *str) {
  static float minu;
  static float degr;
  char *dp = strchr( str, '.');  // point to decimal
  if( dp == NULL)
    return( 0.0);
  dp -= 2;              // point to minutes
  minu = atof(dp);      // convert floating minutes
  *dp = '\0';           // terminate degrees
  degr = atof( str);    // convert float degrees
  degr += minu / 60.0;  // add minutes
  return degr;          // return result
}

#endif

void flush() {
#ifdef USE_GPS
  while( Serial1.available())
    Serial1.read();
#endif
}




void setup() {

  pinMode( A0, OUTPUT);
  digitalWrite( A0, LOW);

#ifdef USE_SERIAL
  Serial.begin(9600);
  while (!Serial) {
    ;
  }
#endif
  
#ifdef USE_GPS  
  Serial1.begin(9600);
  flush();
#endif

  pinMode( LED_BUILTIN, OUTPUT);

  oled_init();

  oled_clear();		// clear screen
  oled_print( 0, "TownFinder(TM) 2.0");
  delay(1000);

  oled_clear();		// clear screen
  oled_print( 0, "Initializing...");
  delay(1000);

#ifdef USE_SERIAL
  Serial.print("Initializing SD card...");
#endif
  // see if the card is present and can be initialized:
  if (!SD.begin(chipSelect)) {
#ifdef USE_SERIAL
    Serial.println("Card failed, or not present");
#endif
    oled_clear();		// clear screen
    oled_print( 0, "SD Fail");
    while (1)
      ;
  } else {
#ifdef USE_SERIAL
    Serial.println("card initialized.");
#endif
  }

  if( !SD.exists("STUFF.REE") ||  !SD.exists("STUFF.DAT") ||
      !SD.exists("STUFF.VRT") ||  !SD.exists("STUFF.PRT")
#ifdef USE_ZONE
      || !SD.exists("ZONE.REE") ||  !SD.exists("ZONE.DAT") ||
      !SD.exists("ZONE.VRT") ||  !SD.exists("ZONE.PRT")
#endif
      ) {
    oled_clear();		// clear screen
    oled_print( 0, "Missing File!");

    while(1)
      ;
    
  } else {
    ft = SD.open("STUFF.REE");
    fd = SD.open("STUFF.DAT");
    fv = SD.open("STUFF.VRT");
    fa = SD.open("STUFF.PRT");
#ifdef USE_ZONE
    zt = SD.open("ZONE.REE");
    zd = SD.open("ZONE.DAT");
    zv = SD.open("ZONE.VRT");
    za = SD.open("ZONE.PRT");
#endif
  }


  oled_clear();		// clear screen
  oled_print( 0, "Ready...");
  delay(1000);

} // setup()

int loop_count = 0;
char *gpsTime;
float floatLat, floatLon;

void loop() {
  ++loop_count;

#ifdef USE_GPS
  gpsTime = GPS_fix( &floatLat, &floatLon);
#endif
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

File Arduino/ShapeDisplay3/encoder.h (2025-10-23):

#ifndef ENCODER_H_INCLUDED
#define ENCODER_H_INCLUDED

#include <RotaryEncoder.h>

#define ENC_A 12
#define ENC_B 11
#define ENC_GRN 1
#define ENC_RED 2
#define ENC_SW 3

RotaryEncoder *encoder = nullptr;

volatile int iCount = 0;

void checkPosition() {
  encoder->tick();
  ++iCount;
}

void encoder_setup() {
  pinMode( ENC_A, INPUT_PULLUP);
  pinMode( ENC_B, INPUT_PULLUP);
  pinMode( ENC_SW, INPUT_PULLUP);
  pinMode( ENC_RED, OUTPUT);
  pinMode( ENC_GRN, OUTPUT);

  encoder = new RotaryEncoder( ENC_A, ENC_B, RotaryEncoder::LatchMode::FOUR3);
  // this doesn't seem to work for some reason
  attachInterrupt( digitalPinToInterrupt(ENC_A), checkPosition, CHANGE);
  attachInterrupt( digitalPinToInterrupt(ENC_B), checkPosition, CHANGE);
}


#endif

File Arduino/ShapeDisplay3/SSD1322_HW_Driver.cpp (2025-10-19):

/**
 ****************************************************************************************
 *
 * \file SSD1322_HW_Driver.cpp
 *
 * \brief Hardware dependent functions for SSD1322 OLED display.
 *
 * This file contains functions that rely on hardware of used MCU. In this example functions
 * are filled with STM32F411RE hardware implementation. To use this library on any other MCU
 * you just have to provide its hardware implementations of functions from this file and higher
 * level functions should work without modification.
 *
 * Copyright (C) 2020 Wojciech Klimek
 * MIT license:
 * https://github.com/wjklimek1/SSD1322_OLED_library
 *
 * Modified for use in Arduino by Eric Hazen
 ****************************************************************************************
 */

//=================== Include hardware HAL libraries =====================//
#include <Arduino.h>
#include <SPI.h>
#include "SSD1322_HW_Driver.h"

//
// define our pins
//
const int OLED_DC_PIN = 5;	/* data/control */
const int OLED_nRST_PIN = 4;	/* reset */
const int OLED_nCS_PIN = 6;	/* chip select */

// #define OUR_SPI_SETTINGS SPISettings(10000000,MSBFIRST,SPI_MODE3)
#define OUR_SPI_SETTINGS SPISettings(4000000,MSBFIRST,SPI_MODE0)

//====================== Initialize Hardware ======================//
void SSD1322_HW_Init() {
  pinMode( OLED_DC_PIN, OUTPUT);
  pinMode( OLED_nRST_PIN, OUTPUT);
  pinMode( OLED_nCS_PIN, OUTPUT);

  digitalWrite( OLED_DC_PIN, LOW);
  digitalWrite( OLED_nRST_PIN, HIGH);
  digitalWrite( OLED_nCS_PIN, HIGH);

  SPI.begin();
}

//====================== CS pin low ========================//
/**
 *  @brief Drives CS (Chip Select) pin of SPI interface low.
 *
 *  CS pin may be also signed as "SS" or "NSS"
 */
void SSD1322_HW_drive_CS_low()
{
  digitalWrite( OLED_nCS_PIN, LOW);
}

//====================== CS pin high ========================//
/**
 *  @brief Drives CS (Chip Select) pin of SPI interface high.
 *
 *  CS pin may be also signed as "SS" or "NSS"
 */
void SSD1322_HW_drive_CS_high()
{
  digitalWrite( OLED_nCS_PIN, HIGH);
}

//====================== DC pin low ========================//
/**
 *  @brief Drives DC (Data/Command) pin of OLED driver low.
 *
 *  High state is for data and low state is for command.
 */
void SSD1322_HW_drive_DC_low()
{
  digitalWrite( OLED_DC_PIN, LOW);
}

//====================== DC pin high ========================//
/**
 *  @brief Drives DC (Data/Command) pin of of OLED driver high.
 *
 *  High state is for data and low state is for command.
 */
void SSD1322_HW_drive_DC_high()
{
  digitalWrite( OLED_DC_PIN, HIGH);
}

//====================== RESET pin low ========================//
/**
 *  @brief Drives RESET pin of of OLED driver low.
 *
 *  Logic low on RESET resets OLED driver.
 */
void SSD1322_HW_drive_RESET_low()
{
  digitalWrite( OLED_nRST_PIN, LOW);
}

//====================== RESET pin high ========================//
/**
 *  @brief Drives RESET pin of of OLED driver high.
 *
 *  Logic low on RESET resets OLED driver.
 */
void SSD1322_HW_drive_RESET_high()
{
  digitalWrite( OLED_nRST_PIN, HIGH);
}

//====================== Send single SPI byte ========================//
/**
 *  @brief Transmits single byte through SPI interface.
 *
 *  @param[in] byte_to_transmit byte that will be transmitted through SPI interface
 */
void SSD1322_HW_SPI_send_byte(uint8_t byte_to_transmit)
{
  SPI.beginTransaction(OUR_SPI_SETTINGS);
  SPI.transfer( byte_to_transmit);
  SPI.endTransaction();
}

//====================== Send array of SPI bytes ========================//
/**
 *  @brief Transmits array of bytes through SPI interface.
 *
 *  @param[in] array_to_transmit array of bytes that will be transmitted through SPI interface
 *  @param[in] array_size amount of bytes to transmit
 */
void SSD1322_HW_SPI_send_array(uint8_t *array_to_transmit, uint32_t array_size)
{
  SPI.beginTransaction(OUR_SPI_SETTINGS);
  for( uint32_t i=0; i<array_size; i++)
    SPI.transfer( array_to_transmit[i]);
  SPI.endTransaction();
}

//====================== Milliseconds delay ========================//
/**
 *  @brief Wait for x milliseconds.
 *
 *  NOTE: This function is only used in initialization sequence to pull reset down and high
 *  and later to wait for Vdd stabilization. It takes time ONLY on startup (around 200ms)
 *  and is NOT USED during normal operation.
 *
 *  @param[in] milliseconds time to wait
 */
void SSD1322_HW_msDelay(uint32_t milliseconds)
{
  for( int i=0; i<milliseconds; i++)
    delay(1);
}

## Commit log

2025-09-10 create repo, upload some OPs models
    [Single_Din_Pocket.stl, Single_Din_with_Switch_and_LCD.stl]
2025-09-14 working on case
    [din.3mf, din.stl, mount.scad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]
2025-09-15 working on mount
    [mount.scad, mount.stl]
2025-09-15 working on front panel model
    [EC12 Encoder 10mm 3pin.stp, LCD_16x2_sparkfun.scad, Unnamed-MKRZero_V5.0.stl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]
2025-09-15 rename KiCAD project
    [EC12 Encoder 10mm 3pin.stp, LCD_16x2_sparkfun.scad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]
2025-09-15 working on PCB
    [car-control.kicad_sch]
2025-09-15 working on layout
    [car-control.kicad_pcb, car-control.kicad_sch]
2025-09-16 working on layout, move USB
    [USB-A-S-F-B-VT--3DModel-STEP-269445.STEP, USB3131-30-0230-A_REVB.step, car-control.kicad_pcb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]
2025-09-20 PCB done?
    [car-control-B_Cu.gbr, car-control-B_Mask.gbr, car-control-B_Silkscreen.gbr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]
2025-09-20 latest mount
    [car-control.kicad_pcb, new_mount.3mf, new_mount.scad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]
2025-09-22 updates to case
    [car-control.kicad_sch, new_mount.scad, new_mount.stl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]
2025-09-22 standoffs, final? gerbers
    [car-control-B_Cu.gbr, car-control-B_Mask.gbr, car-control-B_Silkscreen.gbr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]
2025-09-26 initial software, fix layout
    [car-control.kicad_pcb, car-control.kicad_sch]
2025-09-26 PCB V1.0 as built
    [car-control-B_Cu.gbr, car-control-B_Mask.gbr, car-control-B_Silkscreen.gbr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]
2025-09-29 adding back CSV files, working index?
    [fips.csv, fips50.csv, grid.csv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]
2025-09-30 working with qsort
    [places48.csv, places_all.csv, places_ma_counties.csv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]
2025-09-30 working on FindLocs.ino
    [places.csv, places_states_only.csv]
2025-10-01 Old FindLocs moved to FindLocsSerial, FindLocs compiles now
    [panel.stl, puter.scad]
2025-10-02 works (is) but crashes after 3 updates
    [FindLocs.ino]
2025-10-05 tweaking the display
    [temp_places.csv]
2025-10-06 fix lip on front panel
    [puter.scad]
2025-10-06 tweaking front panel
    [puter.scad, puter.stl]
2025-10-08 tweaking the dimensions
    [box.stl, box_fast.stl, puter.scad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]
2025-10-14 last enclosure tweaks
    [box.stl, panel.stl, puter.scad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]
2025-10-14 update panel and box
    [box.stl, car-control.kicad_sch, panel.stl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]
2025-10-15 label.scad has text labels on front panel
    [label.scad]
2025-10-16 readme, diners
    [diners.csv, diners_cleaned_brookline_30mi.csv, puter.scad]
2025-10-19 working on V2 software
    [AIRPORT.CSV, CONFIG.CSV, GRID.CSV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]
2025-10-23 ControlTest working with interrupts
2025-10-23 shaft encoder readout in FindLocs2
2025-10-23 working on groups
    [AIRPORT.CSV, GRID.CSV]
2025-11-30 about to re-work lat/lon storage
    [STATES.PRT]
2025-12-01 maybe some bugs in new file format
    [STATES.PRT]
2025-12-11 fix some bugs
    [STATES.PRT]
2025-12-11 fixed bug, need to work on merge
    [STATES.PRT]
2025-12-14 initial working? desktop version
    [COUNTY.PRT, CT.PRT, MA.PRT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]
2025-12-15 debugging the arduino
    [COUNTY..PRT, COUNTY.PRT, PLACE.PRT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]
2025-12-15 initial arduino version working
2025-12-20 Audio PCB, download TZ shapefile, update notes
    [CVS-1508_CUD.step, box.stl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]
2025-12-22 version 1.2
    [STUFF.PRT, ZONE.PRT]
2025-12-23 Rev 1.3 - add Boston neighborhoods
    [BOSTON.PRT, STUFF.PRT]
2025-12-23 add some more databases
    [NYBB.PRT, nybb_convert.ods, puter.stl]
2025-12-24 WhyNoDisplay working with timer and oled
2026-01-12 starting work on sound
    [puter.scad]
2026-01-14 add some dims
    [gps_audio.kicad_pcb]
2026-01-15 Add speaker holder proto
    [speaker_older.stl]
2026-01-18 V2.0 with sound as ShapeDisplay2
    [gps_audio-Edge_Cuts.dxf, gps_audio-F_Mask.dxf, gps_audio-F_Paste.dxf]
2026-01-24 Deploy version with sound
    [panel.stl, puter.scad, puter.stl]
2026-04-17 working on MA towns
    [MASS.PRT, STUFFZ.PRT]
2026-04-18 Add MA towns
    [MASS.PRT, STUFFZ.PRT]
2026-07-02 update SW
    [COUNTY..PRT, STUFF.PRT]
2026-08-19 DXF of panel
    [front_panel.dxf, puter.scad]
